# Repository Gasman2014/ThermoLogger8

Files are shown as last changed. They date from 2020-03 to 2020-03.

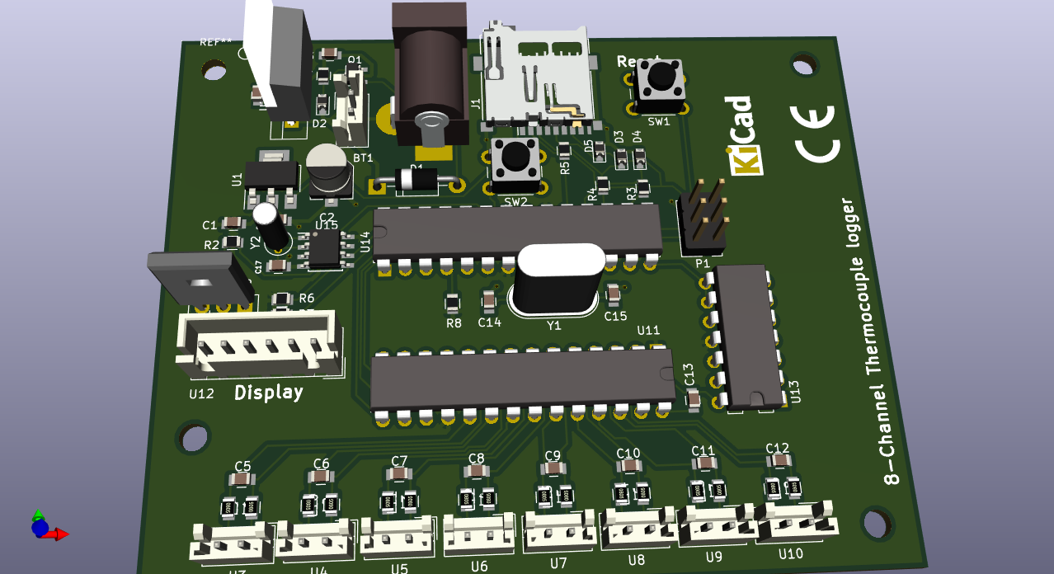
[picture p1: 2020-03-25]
Ver_5V/Renders:STEP/ca9ed02408.png

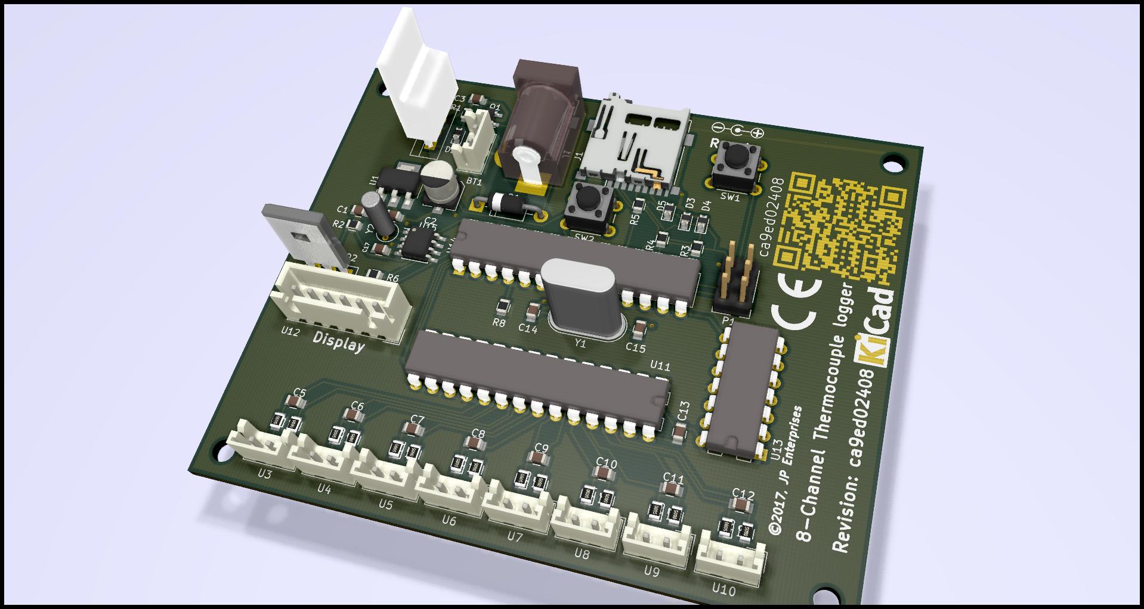
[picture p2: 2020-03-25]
Ver_5V/Renders:STEP/ca9ed02408.jpg

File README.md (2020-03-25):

# ThermoLogger8

Just quickly pushed this repo if anyone is interested. It works in bradboard format and I have designed a PCB in KiCad. There is a 5v and 
a 3.3v version depending on choice of MC. I have been using Fosil as a VCS for this project and have just pushed the whole repo to GitHub.
If you are interested in the development history I could add the Fossil.repo.

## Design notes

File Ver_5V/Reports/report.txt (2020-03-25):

Info: Reading netlist file “/Users/johnpateman/EDA_Workspace/Projects/Thermocouple_datalogger/Ver_5V/ThermocoupleLogger.net”.

Info: Using references to match components and footprints.

Warning: Footprint of symbol "P2" changed: board footprint "Connectors_JST:JST_XH_B04B-XH-A_04x2.50mm_Straight", netlist footprint "Connector_JST:JST_XH_B04B-XH-A_1x04_P2.50mm_Vertical"

Warning: Footprint of symbol "C3" changed: board footprint "Capacitors_SMD:C_0805", netlist footprint "Capacitor_SMD:CP_Elec_4x4.5"

Warning: Footprint of symbol "C4" changed: board footprint "Capacitors_SMD:C_0805", netlist footprint "Capacitor_SMD:CP_Elec_4x4.5"

Info: Checking netlist symbol footprint "BT1:/583C9FB7/5930D2E0:Connectors_JST:JST_XH_B02B-XH-A_02x2.50mm_Straight".

Info: Checking netlist symbol footprint "BT2:/589D87C6/589D8986:Battery_Holders:Keystone_103_1x20mm-CoinCell".

Info: Checking netlist symbol footprint "C1:/583C9FB7/5915D301:Capacitors_SMD:C_0805".

Info: Checking netlist symbol footprint "C2:/583C9FB7/59526106:Capacitors_SMD:CP_Elec_5x5.3".

Info: Checking netlist symbol footprint "C3:/583C9FB7/594D1F83:Capacitor_SMD:CP_Elec_4x4.5".

Changing footprint "C3:/583C9FB7/594D1F83" value from "0.33uF" to "1uF".

Info: Checking netlist symbol footprint "C4:/583C9FB7/589F9200:Capacitor_SMD:CP_Elec_4x4.5".

Changing footprint "C4:/583C9FB7/589F9200" value from "0.1uF" to "10uF".

Info: Checking netlist symbol footprint "C5:/589CE548/589D5633:Capacitors_SMD:C_0805".

Info: Checking netlist symbol footprint "C6:/589CE548/589D5A27:Capacitors_SMD:C_0805".

Info: Checking netlist symbol footprint "C7:/589CE548/589D5A90:Capacitors_SMD:C_0805".

Info: Checking netlist symbol footprint "C8:/589CE548/589D5AFD:Capacitors_SMD:C_0805".

Info: Checking netlist symbol footprint "C9:/589CE548/589D5B98:Capacitors_SMD:C_0805".

Info: Checking netlist symbol footprint "C10:/589CE548/589D9FEC:Capacitors_SMD:C_0805".

Info: Checking netlist symbol footprint "C11:/589CE548/589DA065:Capacitors_SMD:C_0805".

Info: Checking netlist symbol footprint "C12:/589CE548/589DA428:Capacitors_SMD:C_0805".

Info: Checking netlist symbol footprint "C13:/589D87C6/5915E444:Capacitors_SMD:C_0805".

Info: Checking netlist symbol footprint "C14:/589D87C6/59161BEE:Capacitors_SMD:C_0805".

Info: Checking netlist symbol footprint "C15:/589D87C6/59161C96:Capacitors_SMD:C_0805".

Info: Checking netlist symbol footprint "C16:/589D87C6/594D3028:Capacitors_SMD:C_0805".

Info: Checking netlist symbol footprint "C17:/589D87C6/594D308E:Capacitors_SMD:C_0805".

Info: Checking netlist symbol footprint "D1:/583C9FB7/594BF20E:Diodes_THT:D_DO-41_SOD81_P10.16mm_Horizontal".

Changing footprint "D1:/583C9FB7/594BF20E" pad "2" net name from "Net-(D1-Pad2)" to "/Thermocouple_PSU/Supply".

Info: Checking netlist symbol footprint "D2:/583C9FB7/594BFB6D:Diodes_SMD:D_SOD-323".

Info: Checking netlist symbol footprint "D3:/589D5546/59314520:Diodes_SMD:D_SOD-123".

Info: Checking netlist symbol footprint "D4:/589D5546/593144F7:Diodes_SMD:D_SOD-123".

Info: Checking netlist symbol footprint "D5:/589D5546/59314274:Diodes_SMD:D_SOD-123".

Info: Checking netlist symbol footprint "J1:/583C9FB7/5930D1C5:Connectors:BARREL_JACK".

Changing footprint "J1:/583C9FB7/5930D1C5" pad "2" net name from "Net-(D1-Pad2)" to "/Thermocouple_PSU/Supply".

Info: Checking netlist symbol footprint "L1:/589CE548/59318E46:Inductor_SMD:L_0805_2012Metric".

Changing footprint "L1:/589CE548/59318E46" value from "150Ω" to "150".

Info: Checking netlist symbol footprint "L2:/589CE548/594D1477:Inductor_SMD:L_0805_2012Metric".

Changing footprint "L2:/589CE548/594D1477" value from "150Ω" to "150".

Info: Checking netlist symbol footprint "L3:/589CE548/594D14C5:Inductor_SMD:L_0805_2012Metric".

Changing footprint "L3:/589CE548/594D14C5" value from "150Ω" to "150".

Info: Checking netlist symbol footprint "L4:/589CE548/594D1517:Inductor_SMD:L_0805_2012Metric".

Changing footprint "L4:/589CE548/594D1517" value from "150Ω" to "150".

Info: Checking netlist symbol footprint "L5:/589CE548/594D156A:Inductor_SMD:L_0805_2012Metric".

Changing footprint "L5:/589CE548/594D156A" value from "150Ω" to "150".

Info: Checking netlist symbol footprint "L6:/589CE548/594D1615:Inductor_SMD:L_0805_2012Metric".

Changing footprint "L6:/589CE548/594D1615" value from "150Ω" to "150".

Info: Checking netlist symbol footprint "L7:/589CE548/594D1669:Inductor_SMD:L_0805_2012Metric".

Changing footprint "L7:/589CE548/594D1669" value from "150Ω" to "150".

Info: Checking netlist symbol footprint "L8:/589CE548/594D16C4:Inductor_SMD:L_0805_2012Metric".

Changing footprint "L8:/589CE548/594D16C4" value from "150Ω" to "150".

Info: Checking netlist symbol footprint "L9:/589CE548/594D1429:Inductor_SMD:L_0805_2012Metric".

Changing footprint "L9:/589CE548/594D1429" value from "150Ω" to "150".

Info: Checking netlist symbol footprint "L10:/589CE548/594D1721:Inductor_SMD:L_0805_2012Metric".

Changing footprint "L10:/589CE548/594D1721" value from "150Ω" to "150".

Info: Checking netlist symbol footprint "L11:/589CE548/594D177B:Inductor_SMD:L_0805_2012Metric".

Changing footprint "L11:/589CE548/594D177B" value from "150Ω" to "150".

Info: Checking netlist symbol footprint "L12:/589CE548/594D17DD:Inductor_SMD:L_0805_2012Metric".

Changing footprint "L12:/589CE548/594D17DD" value from "150Ω" to "150".

Info: Checking netlist symbol footprint "L13:/589CE548/594D183D:Inductor_SMD:L_0805_2012Metric".

Changing footprint "L13:/589CE548/594D183D" value from "150Ω" to "150".

Info: Checking netlist symbol footprint "L14:/589CE548/594D18A4:Inductor_SMD:L_0805_2012Metric".

Changing footprint "L14:/589CE548/594D18A4" value from "150Ω" to "150".

Info: Checking netlist symbol footprint "L15:/589CE548/594D190A:Inductor_SMD:L_0805_2012Metric".

Changing footprint "L15:/589CE548/594D190A" value from "150Ω" to "150".

Info: Checking netlist symbol footprint "L16:/589CE548/594D1971:Inductor_SMD:L_0805_2012Metric".

Changing footprint "L16:/589CE548/594D1971" value from "150Ω" to "150".

Info: Checking netlist symbol footprint "P1:/589D87C6/589E4CA3:Pin_Headers:Pin_Header_Straight_2x03_Pitch2.54mm".

Info: Checking netlist symbol footprint "P2:/589D87C6/5AF4BC3D:Connector_JST:JST_XH_B04B-XH-A_1x04_P2.50mm_Vertical".

Changing footprint "P2:/589D87C6/589D89DF" value from "CONN_01X04" to "Conn_01x04".

Info: Changing component path “P2:/589D87C6/589D89DF” to “/589D87C6/5AF4BC3D”.

Info: Checking netlist symbol footprint "Q1:/583C9FB7/594BC4B0:TO_SOT_Packages_SMD:TSOT-23".

Changing footprint "Q1:/583C9FB7/594BC4B0" pad "1" net name from "Net-(D1-Pad2)" to "/Thermocouple_PSU/Supply".

Info: Checking netlist symbol footprint "Q2:/589D5546/589EBCEC:TO_SOT_Packages_THT:TO-126_Vertical".

Info: Checking netlist symbol footprint "R1:/583C9FB7/594BF93F:Resistors_SMD:R_0805".

Info: Checking netlist symbol footprint "R2:/589D5546/589EBC96:Resistors_SMD:R_0805".

Info: Checking netlist symbol footprint "R3:/589D5546/59314B9F:Resistors_SMD:R_0805".

Info: Checking netlist symbol footprint "R4:/589D5546/59314AC7:Resistors_SMD:R_0805".

Info: Checking netlist symbol footprint "R5:/589D5546/59314C06:Resistors_SMD:R_0805".

Info: Checking netlist symbol footprint "R6:/589D87C6/589D89D8:Resistors_SMD:R_0805".

Info: Checking netlist symbol footprint "R7:/589D87C6/589D89CE:Resistors_SMD:R_0805".

Info: Checking netlist symbol footprint "R8:/589D87C6/589D89B6:Resistors_SMD:R_0805".

Info: Checking netlist symbol footprint "SW1:/589D87C6/59308FE2:Buttons_Switches_THT:SW_PUSH_6mm_h5mm".

Info: Checking netlist symbol footprint "SW2:/589D87C6/5930906F:Buttons_Switches_THT:SW_PUSH_6mm_h5mm".

Info: Checking netlist symbol footprint "U1:/583C9FB7/59525E1F:TO_SOT_Packages_SMD:SOT-223".

Info: Checking netlist symbol footprint "U2:/583C9FB7/594D2B25:TO_SOT_Packages_THT:TO-220_Vertical".

Info: Checking netlist symbol footprint "U3:/589CE548/589CECB5:Connectors_JST:JST_XH_B02B-XH-A_02x2.50mm_Straight".

Info: Checking netlist symbol footprint "U4:/589CE548/589CECBF:Connectors_JST:JST_XH_B02B-XH-A_02x2.50mm_Straight".

Info: Checking netlist symbol footprint "U5:/589CE548/589CECC9:Connectors_JST:JST_XH_B02B-XH-A_02x2.50mm_Straight".

Info: Checking netlist symbol footprint "U6:/589CE548/589CECD3:Connectors_JST:JST_XH_B02B-XH-A_02x2.50mm_Straight".

Info: Checking netlist symbol footprint "U7:/589CE548/589CECDD:Connectors_JST:JST_XH_B02B-XH-A_02x2.50mm_Straight".

Info: Checking netlist symbol footprint "U8:/589CE548/589CECE7:Connectors_JST:JST_XH_B02B-XH-A_02x2.50mm_Straight".

Info: Checking netlist symbol footprint "U9:/589CE548/589CECF1:Connectors_JST:JST_XH_B02B-XH-A_02x2.50mm_Straight".

Info: Checking netlist symbol footprint "U10:/589CE548/589CECFB:Connectors_JST:JST_XH_B02B-XH-A_02x2.50mm_Straight".

Info: Checking netlist symbol footprint "U11:/589CE548/589D71A8:Housings_DIP:DIP-28_W15.24mm".

Info: Checking netlist symbol footprint "U12:/589D5546/589D6D78:Connectors_JST:JST_XH_B06B-XH-A_06x2.50mm_Straight".

Info: Checking netlist symbol footprint "U13:/589D87C6/589E58D9:Housings_DIP:DIP-14_W7.62mm".

Info: Checking netlist symbol footprint "U14:/589D87C6/593091B0:Housings_DIP:DIP-28_W7.62mm".

Info: Checking netlist symbol footprint "U15:/589D87C6/593095B6:Housings_SOIC:SOIC-8_3.9x4.9mm_Pitch1.27mm".

Info: Checking netlist symbol footprint "XS1:/589D5546/59544647:jp_personal:Conn_uSDcard".

Info: Checking netlist symbol footprint "Y1:/589D87C6/589E8900:Crystals:Crystal_HC49-U_Vertical".

Info: Checking netlist symbol footprint "Y2:/589D87C6/589D897F:Crystals:Crystal_Round_d3.0mm_Vertical".

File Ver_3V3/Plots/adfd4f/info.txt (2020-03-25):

uuid:         adfd4f66951eeb5335d1c4a91e0210d5d108aa21 2017-11-17 14:26:38 UTC
parent:       d7c0fee4f85c9370c295e011c4474d3fdc0f855e 2017-11-03 09:44:51 UTC
tags:         parallel_connector
comment:      Adjusted footprint for battery to JST-XH series (user: johnpateman)

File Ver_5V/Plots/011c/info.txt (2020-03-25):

uuid:         011c27aa1c76feabf7278f71abef9c959f46e682 2018-12-18 12:02:45 UTC
parent:       52bd0d96c514364f6365ff9b00088230d3ec4453 2018-12-17 20:01:36 UTC
tags:         Ver_5V
comment:      Updated entire board with Kicad V5.0.2 stock footprints (apart from custom SD Card) (user: johnpateman)

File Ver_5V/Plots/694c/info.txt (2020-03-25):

uuid:         694c0817d49da92233c9e31c0feafe5217195195 2018-12-01 09:59:20 UTC
parent:       5034922709994dd389909f162e60e1b737ea69a4 2018-11-30 19:22:05 UTC
child:        162a23e4f3287c9c34212c83937c62a5d8ec3218 2018-12-17 20:04:35 UTC
tags:         parallel_connector
comment:      Updated multiple components with new component numbers to match PartKeepr database. Rerun KiBOM. The .csv file in this commit has had the Display line removed.
              Need to remove the display line as this seem to cause the K2PK script to fail - it continues to look up all component in the database. Probably related to this
              component not having a specific footprint. (user: johnpateman)

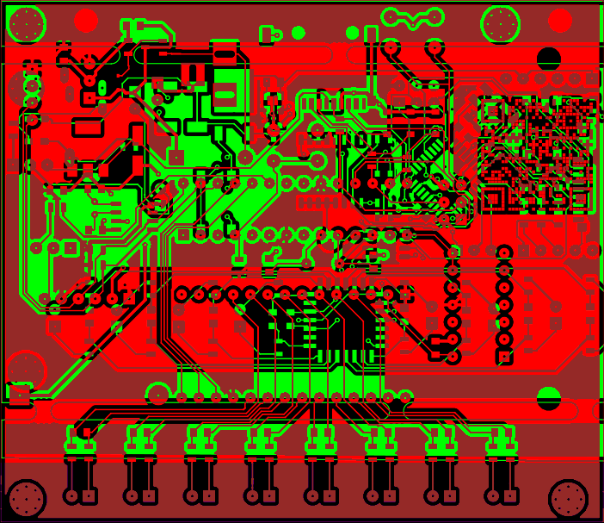
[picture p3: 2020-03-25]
Ver_3V3/Plots/diff-adfd4f-620aab/ThermocoupleLogger-F_Cu.png

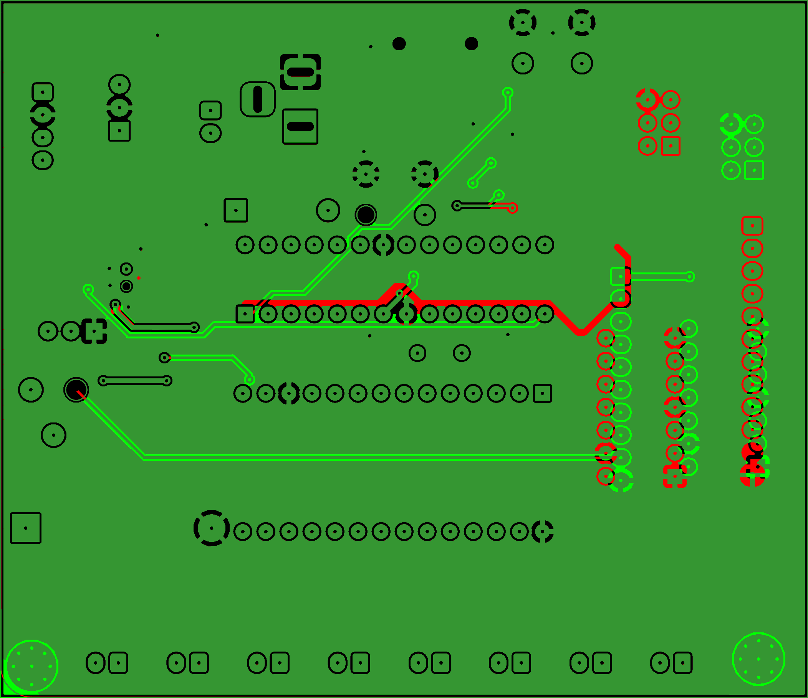
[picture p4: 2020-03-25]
Ver_5V/Plots/diff-3c9fec-b2096b/ThermocoupleLogger-B_Cu.png

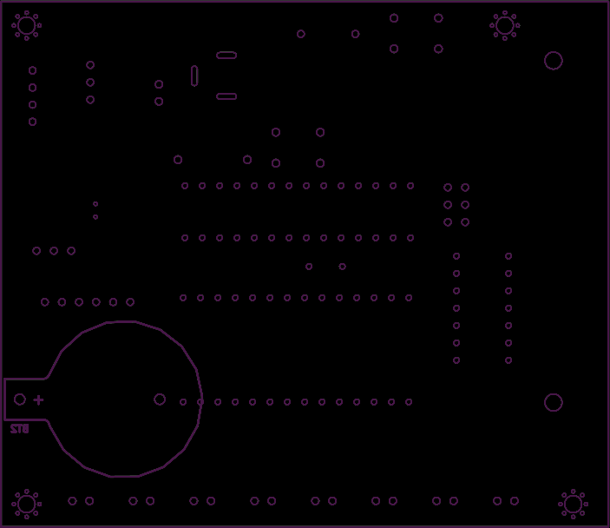
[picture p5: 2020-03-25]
Ver_3V3/Plots/620aab/ThermocoupleLogger-B_SilkS.png

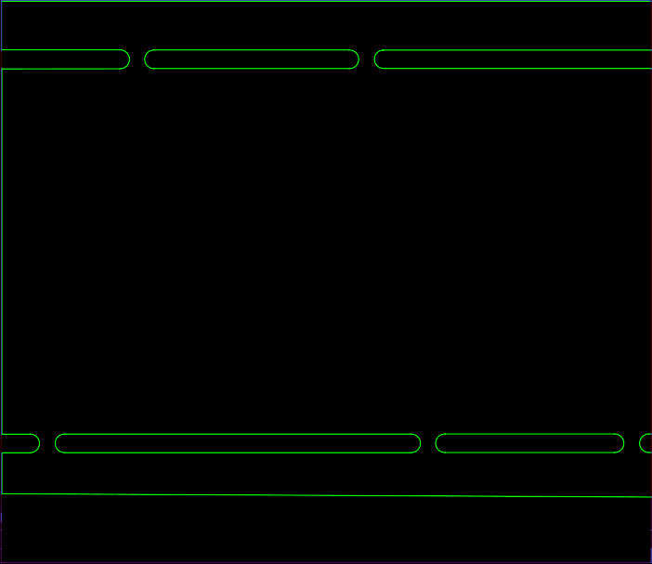
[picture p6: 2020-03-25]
Ver_3V3/Plots/diff-adfd4f-620aab/ThermocoupleLogger-B_Adhes.png

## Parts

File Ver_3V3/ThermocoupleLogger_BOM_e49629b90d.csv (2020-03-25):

Component | Description | Part | References | Value | Footprint | Quantity Per PCB | Datasheet | Part# | Placement | Package_ID | Characteristics | C3 C16 C17 C18 C20 C21 C22 | 100nF 0805 | 7 | C_0805 | 7
1 | Multiple-cell battery | Battery | BT2 | 3V [CR2032] | Keystone_106_1x20mm-CoinCell | 1 |  | KEYSTONE 103 | - | - | - | C6 C7 C8 C9 C10 C11 C12 C13 C14 C15 C19 | 10nF 0805 | 11 | C_0805 | 11
2 | Multiple-cell battery | Battery | BT1 | Battery | JST_XH_B02B-XH-A_1x02_P2.50mm_Vertical | 1 |  | B2B-XH-A(LF)(SN) | - | - | - | C4 | 10uF 0805 | 1 | C_0805 | 1
3 | Unpolarized capacitor, small symbol | C_Small | C3 C16 C17 C18 C20 C21 C22 | 100nF | C_0805 | 7 |  | - | - | - | - | C5 | 1uF 0805 | 1 | C_0805 | 1
4 | Polarized capacitor, small symbol | CP_Small | C1 C2 | 100uF | CP_Elec_5x5.3 | 2 |  | EEEFT1C101AR | - | - | - | D2 D3 | 1N4448W-7-F SOD-123 | 2 | D_ | 2
5 | Unpolarized capacitor, small symbol | C_Small | C6 C7 C8 C9 C10 C11 C12 C13 C14 C15 C19 | 10nF | C_0805 | 11 |  | - | - | - | - | IC1 | ATMEGA328-P | 1 | TQFP-32_7x7mm_Pitch0.8mm | 1
6 | Polarized capacitor, small symbol | CP_Small | C4 | 10uF | C_0805 | 1 |  | - | - | - | - | J1 | FC68127 | 1 | CLIFF_FC68127 | 1
7 | Unpolarized capacitor, small symbol | C_Small | C5 | 1uF | C_0805 | 1 |  | - | - | - | - | L1 L2 L3 L4 L5 L6 L7 L8 L9 L10 L11 L12 L13 L14 L15 L16 | Ferrite 100 Ohms 10MHz 0805 | 16 | L_0805 | 16
8 | SD Card Reader | SD_Card | CON1 | SD_Card | Conn_uSDcard | 1 | http://portal.fciconnect.com/Comergent//fci/drawing/10067847.pdf | SD_Card[uSD] | - | - | - | P1 | Conn_02x03_Top_Bottom | 1 | PinHeader_2x03_P2.54mm_Vertical | 1
9 | 50V 1A General Purpose Rectifier Diode, DO-41 | 1N4001 | D2 D3 | 1N4448W-7-F | D_SOD-123 | 2 | http://www.vishay.com/docs/88503/1n4001.pdf | 1N4448W-7-F | - | - | - | Q1 | MMBT3904LT1G | 1 | SOT-23 | 1
10 | Dual LED, common cathode on pin 2 | LED_Dual_ACA | D1 | LED_Dual_ACA | LED_D3.0mm-3 | 1 |  | L-93WEGW | - | - | - | R3 R4 R10 | 10k | 3 | R_0805 | 3
11 |  | ATMEGA328P-AU-RESCUE-ThermocoupleLogger | IC1 | ATMEGA328-P | TQFP-32_7x7mm_Pitch0.8mm | 1 |  | ATMEGA328P-AU | - | - | - | R5 R6 R7 | 22k | 3 | R_0805 | 3
12 | Generic connector, single row, 01x03, script generated (kicad-library-utils/schlib/autogen/connector/) | Conn_01x03 | J2 | CONN_01X03 | Pin_Header_Straight_1x03_Pitch2.54mm | 1 |  | B3B-XH-A(LF)(SN) | - | - | - | R11 | 330R | 1 | R_0805 | 1
13 | Generic connector, single row, 01x05, script generated (kicad-library-utils/schlib/autogen/connector/) | Conn_01x05 | J3 | CONN_01X05 | PinHeader_1x05_P2.54mm_Vertical | 1 |  | B5B-XH-A(LF)(SN) | - | - | - | R8 R9 | 4.7k | 2 | R_0805 | 2
14 | Jack socket, 3.5mm, 4-Pole | FC68127 | J1 | FC68127 | CLIFF_FC68127 | 1 | FC68127 | FC68127 | - | - | - | R1 R2 | 750R | 2 | R_0805 | 2
15 | Ferrite bead, small symbol | Ferrite_Bead_Small | L1 L2 L3 L4 L5 L6 L7 L8 L9 L10 L11 L12 L13 L14 L15 L16 | 100 Ohms 10MHz | L_0805 | 16 |  | MPZ2012S101A | - | - | - | SW2 SW3 | SW_PUSH | 2 | SW_PUSH_6mm_H4.3mm | 2
16 | Generic connector, double row, 02x03, top/bottom pin numbering scheme (row 1: 1...pins_per_row, row2: pins_per_row+1 ... num_pins), script generated (kicad-library-utils/schlib/autogen/connector/) | Conn_02x03_Top_Bottom | P1 | Conn_02x03_Top_Bottom | PinHeader_2x03_P2.54mm_Vertical | 1 |  | 75869-131LF | - | - | - | SW1 | SW_SPST | 1 | JST_XH_B02B-XH-A_1x02_P2.50mm_Vertical | 1
17 | 0.2A Ic, 40V Vce, Small Signal NPN Transistor, SOT-23 | MMBT3904 | Q1 | MMBT3904LT1G | SOT-23 | 1 | http://www.fairchildsemi.com/ds/BC/BC817.pdf | MMBT3904LT1G | - | - | - | U4 | ADG407BPZ | 1 | PLCC-28 | 1
18 | Resistor, small symbol | R_Small | R3 R4 R10 | 10k | R_0805 | 3 |  | - | - | - | - | U13 | DS3231 | 1 | SOIC-16W_7.5x10.3mm_Pitch1.27mm | 1
19 | Resistor, small symbol | R_Small | R5 R6 R7 | 22k | R_0805 | 3 |  | - | - | - | - | U1 | LF50_TO252 | 1 | TO-252-3_TabPin4 | 1
20 | Resistor, small symbol | R_Small | R11 | 330R | R_0805 | 1 |  | - | - | - | - | U14 | MAX31855KASA | 1 | SOIC-8_3.9x4.9mm_P1.27mm | 1
21 | Resistor | R | R8 R9 | 4.7k | R_0805 | 2 |  | - | - | - | - | U2 | RT9166-33GVL | 1 | SOT-23 | 1
22 | Resistor, small symbol | R_Small | R1 R2 | 750R | R_0805 | 2 |  | - | - | - | - | U3 U5 U6 U7 U8 U9 U10 U11 | TC_Connector | 8 | JST_XH_B02B-XH-A_1x02_P2.50mm_Vertical | 8
23 | Push button switch, generic, two pins | SW_Push | SW2 SW3 | SW_PUSH | SW_PUSH_6mm_H4.3mm | 2 |  | SKHHAJA010 | - | - | - | Y1 | Crystal_8MHz | 1 | Crystal_SMD_Abracon_ABM3B-4pin_5.0x3.2mm | 1
24 | Single Pole Single Throw (SPST) switch | SW_SPST | SW1 | SW_SPST | JST_XH_B02B-XH-A_1x02_P2.50mm_Vertical | 1 |  | B2B-XH-A(LF)(SN) | - | - | -
25 | ADG406/407/426_Analog Multiplexer | ADG407 | U4 | ADG407BPZ | PLCC-28 | 1 | http://www.analog.com/media/en/technical-documentation/data-sheets/ADG406_407_426.pdf | ADG407BPZ | - | - | -
26 |  | DS3231M | U13 | DS3231 | SOIC-16W_7.5x10.3mm_Pitch1.27mm | 1 |  | DS3231M+ | - | - | -
28 |  | 7805-RESCUE-ThermocoupleLogger | U1 | LF50_TO252 | TO-252-3_TabPin4 | 1 |  | LF50ABDT-TR | - | - | -
29 | Cold Junction K-type Thermocouple Interface, SPI, SO8 | MAX31855KASA | U14 | MAX31855KASA | SOIC-8_3.9x4.9mm_P1.27mm | 1 | http://datasheets.maximintegrated.com/en/ds/MAX31855.pdf | MAX31855KASA | - | - | -
30 | Low Quiescent Current LDO Regulator, 3.3V, 250 mA, Vin<=16V, SOT-23 | MCP1703A-3302_SOT23 | U2 | RT9166-33GVL | SOT-23 | 1 | http://ww1.microchip.com/downloads/en/DeviceDoc/20005122B.pdf | RT9166-33GVL | - | - | -
31 | TC_Connector | TC_Connector | U3 U5 U6 U7 U8 U9 U10 U11 | TC_Connector | JST_XH_B02B-XH-A_1x02_P2.50mm_Vertical | 8 |  | B2B-XH-A(LF)(SN) | - | - | -
32 | Four pin crystal, GND on pins 2 and 4 | Crystal_GND24 | Y1 | Crystal_8MHz | Crystal_SMD_Abracon_ABM3B-4pin_5.0x3.2mm | 1 |  | ABM3B-8.000MHZ-B2-T |  | - | -
Component Groups: | 32
Component Count: | 79
Fitted Components: | 79
Number of PCBs: | 1
Total components: | 79
Schematic Version: | e49629b90d
Schematic Date: | 11/06/18
BoM Date: | Saturday, 01 December 2018 at 09:49:37
Schematic Source: | /Users/johnpateman/EDA_Workspace/Projects/Thermocouple_datalogger/Ver_3V3/ThermocoupleLogger.sch
KiCad Version: | Eeschema (5.0.1-3-g963ef8bb5)

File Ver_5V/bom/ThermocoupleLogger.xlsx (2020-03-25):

Prj: | 8-Channel Thermocouple Datalogger |  |  |  |  |  | Board Qty: | 100
Co.: | JP Enterprises |  |  |  |  |  | Unit Cost: | $0.00
Prj date: | Friday, 29 June 2018 at 12:55:12 |  |  |  |  |  | Total Cost: | $0.00 |  |  |  | $0.00 | 0 |  |  |  | $0.00 | 0 |  |  |  | $0.00 | 0 |  |  |  | $0.00 | 0 |  |  |  | $0.00 | 0 |  |  |  | $0.00 | 0
$ date: | 2018-07-04 23:36:02
Global Part Info |  |  |  |  |  |  |  |  | Digi-Key |  |  |  |  | Farnell |  |  |  |  | Mouser |  |  |  |  | Newark |  |  |  |  | Rs Components |  |  |  |  | Tme
Refs | Value | Desc | Footprint | Manf | Manf# | Qty | Unit$ | Ext$ | Avail | Purch | Unit$ | Ext$ | Cat# | Avail | Purch | Unit$ | Ext$ | Cat# | Avail | Purch | Unit$ | Ext$ | Cat# | Avail | Purch | Unit$ | Ext$ | Cat# | Avail | Purch | Unit$ | Ext$ | Cat# | Avail | Purch | Unit$ | Ext$ | Cat#
BT1 | 9V | - | Connectors_JST:JST_XH_B02B-XH-A_02x2.50mm_Straight |  | JST-B2B-XH-A | 0 | $0.00 | $0.00
BT2 | Battery | - | Battery_Holders:Keystone_103_1x20mm-CoinCell |  | KEYSTONE 103 | 0 | $0.00 | $0.00
C1 | 470nF | - | Capacitors_SMD:C_0805 |  | - | 0 | $0.00 | $0.00
C13 | 10nF | - | Capacitors_SMD:C_0805 |  | C_0805_X7R_10NF | 0 | $0.00 | $0.00
C14,C15 | 18pF | - | Capacitors_SMD:C_0805 |  | - | 0 | $0.00 | $0.00
C16,C17 | 12.5pF | - | Capacitors_SMD:C_0805 |  | - | 0 | $0.00 | $0.00
C2 | 47uF | - | Capacitors_SMD:CP_Elec_5x5.3 |  | CPE_C_47UF_16V | 0 | $0.00 | $0.00
C3 | 1uF | - | Capacitors_SMD:C_0805 |  | - | 0 | $0.00 | $0.00
C4 | 10uF | - | Capacitor_SMD:CP_Elec_4x5.4 |  | - | 0 | $0.00 | $0.00
C5-C12 | 10nF | C5-C10,C12: - C11: X7R | Capacitors_SMD:C_0805 |  | - | 0 | $0.00 | $0.00
D1 | 1N4007 | - | Diodes_THT:D_DO-41_SOD81_P10.16mm_Horizontal |  | 1N4007 | 0 | $0.00 | $0.00 |  |  |  |  |  | NonStk |  |  |  | 1467514 (http://it.farnell.com/on-semiconductor/1n4007/diodo-standard-1a-1000v-do-41/dp/1467514?st=1N4007) |  |  |  |  |  | NonStk |  | $0.00 | $0.00 | 10M2939 (http://www.newark.com/nte-electronics/1n4007/standard-diode-1a-1kv-do-41/dp/10M2939?st=1N4007) |  |  |  |  |  | 492550 |  | $0.00 | $0.00 | 1N4007-DC (https://www.tme.eu/en/details/1n4007-dc/tht-universal-diodes/dc-components/1n4007/)
D2 | 9V | - | Diodes_SMD:D_SOD-323 |  | BAT60JFILM | 0 | $0.00 | $0.00 | 40878 |  | $0.00 | $0.00 | 497-3707-1-ND (https://www.digikey.com/product-detail/en/stmicroelectronics/BAT60JFILM/497-3707-1-ND/686425) |  |  |  |  |  |  |  |  |  |  |  |  |  |  |  | 800 |  | $0.00 | $0.00 | 714-6879 (http://it.rs-online.com/web/p/diodi-rettificatori-e-schottky/7146879/)
D3-D5 | 3.3V | - | Diodes_SMD:D_SOD-123 |  | BZT52C3V3-7-F | 0 | $0.00 | $0.00 | 34534 |  | $0.00 | $0.00 | BZT52C3V3-FDICT-ND (https://www.digikey.com/product-detail/en/diodes-incorporated/BZT52C3V3-7-F/BZT52C3V3-FDICT-ND/717854) | 11859 |  | $0.00 | $0.00 | 1843704 (http://it.farnell.com/diodes-inc/bzt52c3v3-7-f/diodo-zener-3-3v-0-5w-sod-123/dp/1843704?st=BZT52C3V3-7-F) |  |  |  |  |  | 5525 |  | $0.00 | $0.00 | 12T1447 (http://www.newark.com/webapp/wcs/stores/servlet/Search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) | 27000 |  | $0.00 | $0.00 | 122-0905 (http://it.rs-online.com/web/p/diodi-zener/1220905/) | 4430 |  | $0.00 | $0.00 | BZT52C3V3-7-F (https://www.tme.eu/en/details/bzt52c3v3-7-f/smd-zener-diodes/diodes-incorporated/)
J1 | Barrel_Jack | - | Connectors:BARREL_JACK |  | MJ-179PH | 0 | $0.00 | $0.00
L1-L16 | 150 | - | Inductor_SMD:L_0805_2012Metric |  | MPZ2012S101A | 0 | $0.00 | $0.00 | NonStk |  | $0.00 | $0.00 | 445-172903-1-ND (https://www.digikey.com/product-detail/en/tdk-corporation/MPZ2012S101ATD25/445-172903-1-ND/5040534) |  |  |  |  |  |  |  |  |  |  |  |  |  |  |  | NonStk |  | $0.00 | $0.00 | 604-2202 (http://it.rs-online.com/web/c/?searchTerm=MPZ2012S101A)
P1 | CONN_02X03 | - | Pin_Headers:Pin_Header_Straight_2x03_Pitch2.54mm |  | - | 0 | $0.00 | $0.00
P2 | Conn_01x04 | - | Connector_JST:JST_XH_B04B-XH-A_1x04_P2.50mm_Vertical |  | - | 0 | $0.00 | $0.00
Q1 | BS250 | - | TO_SOT_Packages_SMD:TSOT-23 |  | BS250FTA | 0 | $0.00 | $0.00 | 727 |  | $0.00 | $0.00 | BS250FCT-ND (https://www.digikey.com/product-detail/en/diodes-incorporated/BS250FTA/BS250FCT-ND/53566) | 2332 |  | $0.00 | $0.00 | 1843731 (http://it.farnell.com/diodes-inc/bs250fta/mosfet-canale-p-45v-0-09a-sot23/dp/1843731?st=BS250FTA) | 313 |  | $0.00 | $0.00 | 522-BS250FTA (https://eu.mouser.com/Search/Refine.aspx?Keyword=BS250FTA) | 2352 |  | $0.00 | $0.00 | 12T1444 (http://www.newark.com/webapp/wcs/stores/servlet/Search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) | 170 |  |  |  | 215-6593 (http://it.rs-online.com/web/p/transistor-mosfet/2156593/)
Q2 | BD139 | - | TO_SOT_Packages_THT:TO-126_Vertical |  | BD139 | 0 | $0.00 | $0.00 | NonStk |  | $0.00 | $0.00 | 497-6656-5-ND (https://www.digikey.com/product-detail/en/stmicroelectronics/BD139/497-6656-5-ND/1037682) | 2409 |  | $0.00 | $0.00 | 9556052 (http://it.farnell.com/on-semiconductor/bd139g/transistor-npn-to-225aa/dp/9556052?st=BD139) |  |  |  |  |  | NonStk |  | $0.00 | $0.00 | 33X4079 (http://www.newark.com/stmicroelectronics/bd139/bipolar-bjt-single-transistor/dp/33X4079?st=BD139) | NonStk |  |  |  | 314-1823 (http://it.rs-online.com/web/p/transistor-bipolari/3141823/) | NonStk |  | $0.00 | $0.00 | BD139 (https://www.tme.eu/en/details/bd139/npn-tht-transistors/st-microelectronics/)
R1,R2,R8 | 10K | - | Resistors_SMD:R_0805 |  | RC0805JR-0710KL | 0 | $0.00 | $0.00 | NonStk |  | $0.00 | $0.00 | 311-10KARCT-ND (https://www.digikey.com/product-detail/en/yageo/RC0805JR-0710KL/311-10KARCT-ND/731188) | 10301 |  | $0.00 | $0.00 | 9234136 (http://it.farnell.com/yageo/rc0805jr-0710kl/res-film-spesso-10k-5-0-125w-0805/dp/9234136?st=RC0805JR-0710KL) |  |  |  |  |  | 17748 |  | $0.00 | $0.00 | 68R0258 (http://www.newark.com/yageo/rc0805jr-0710kl/res-thick-film-10k-5-0-125w-0805/dp/68R0258?st=RC0805JR-0710KL) |  |  |  |  |  | 523600 |  | $0.00 | $0.00 | RC0805JR-0710K (https://www.tme.eu/en/details/rc0805jr-0710k/0805-smd-resistors/yageo/rc0805jr-0710kl/)
R6,R7 | 5.1K | - | Resistors_SMD:R_0805 |  | RC0805JR-075K1L | 0 | $0.00 | $0.00 | 301483 |  | $0.00 | $0.00 | 311-5.1KARCT-ND (https://www.digikey.com/product-detail/en/yageo/RC0805JR-075K1L/311-5.1KARCT-ND/731285) |  |  |  |  |  |  |  |  |  |  |  |  |  |  |  |  |  |  |  |  | 3000 |  | $0.00 | $0.00 | RC0805JR-075K1 (https://www.tme.eu/en/details/rc0805jr-075k1/0805-smd-resistors/yageo/rc0805jr-075k1l/)
R3-R5 | 220R | - | Resistors_SMD:R_0805 |  | - | 0 | $0.00 | $0.00
SW1,SW2 | SW_Push | - | Buttons_Switches_THT:SW_PUSH_6mm_h5mm |  | - | 0 | $0.00 | $0.00
U1 | LM3940 | - | TO_SOT_Packages_SMD:SOT-223 |  | LM3940IMP-3.3/NOPB | 0 | $0.00 | $0.00 | 13104 |  | $0.00 | $0.00 | LM3940IMP-3.3/NOPBCT-ND (https://www.digikey.com/product-detail/en/texas-instruments/LM3940IMP-3.3-NOPB/LM3940IMP-3.3-NOPBCT-ND/308025) |  |  |  |  |  |  |  |  |  |  |  |  |  |  |  | 2000 |  | $0.00 | $0.00 | 121-8914 (http://it.rs-online.com/web/p/regolatori-di-tensione-low-dropout/1218914/) | NonStk |  | $0.00 | $0.00 | LM3940IMP-3.3 (https://www.tme.eu/en/details/lm3940imp-3.3/ldo-unregulated-voltage-regulators/texas-instruments/lm3940imp-33nopb/)
U11 | ADG407 | - | Housings_DIP:DIP-28_W15.24mm |  | ADG407BNZ | 0 | $0.00 | $0.00 | 57 |  | $0.00 | $0.00 | ADG407BNZ-ND (https://www.digikey.com/products/en?keywords=ADG407BNZ) |  |  |  |  |  |  |  |  |  |  |  |  |  |  |  | 13 |  |  |  | 523-0054 (http://it.rs-online.com/web/p/multiplexer/5230054/)
U12 | I2C_20x4_DISPLAY | - | Connectors_JST:JST_XH_B06B-XH-A_06x2.50mm_Straight |  | JST-B6B-XH-A | 0 | $0.00 | $0.00
U13 | AD595 | - | Housings_DIP:DIP-14_W7.62mm |  | AD595CQ | 0 | $0.00 | $0.00 | 1123 |  | $0.00 | $0.00 | AD595CQ-ND (https://www.digikey.com/products/en?keywords=AD595CQ) | 15 |  | $0.00 | $0.00 | 102052 (http://it.farnell.com/Search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) |  |  |  |  |  | NonStk |  |  |  | 15P0723 (http://www.newark.com/webapp/wcs/stores/servlet/Search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) | 66 |  |  |  | 169-8737 (http://it.rs-online.com/web/p/amplificatori-da-strumentazione/1698737/)
U14 | ATMEGA328P-PU | - | Housings_DIP:DIP-28_W7.62mm |  | ATMEGA328P-PU | 0 | $0.00 | $0.00 | 17406 |  | $0.00 | $0.00 | ATMEGA328P-PU-ND (https://www.digikey.com/products/en?keywords=ATMEGA328P-PU) |  |  |  |  |  |  |  |  |  |  | 5810 |  | $0.00 | $0.00 | 68T2944 (http://www.newark.com/webapp/wcs/stores/servlet/Search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) | NonStk |  | $0.00 | $0.00 | 921-4545 (http://it.rs-online.com/web/p/microcontroller/9214545/) | 2388 |  | $0.00 | $0.00 | ATMEGA328P-PU (https://www.tme.eu/en/details/atmega328p-pu/8-bit-avr-family/microchip-atmel/)
U15 | DS1307+ | - | Housings_SOIC:SOIC-8_3.9x4.9mm_Pitch1.27mm |  | DS1307ZN+ (https://datasheets.maximintegrated.com/en/ds/DS1307.pdf) | 0 | $0.00 | $0.00 | 11632 |  | $0.00 | $0.00 | DS1307ZN+-ND (https://www.digikey.com/product-detail/en/maxim-integrated/DS1307ZN/DS1307ZN-ND/956881) |  |  |  |  |  |  |  |  |  |  |  |  |  |  |  | 13 |  |  |  | 732-7333 (http://it.rs-online.com/web/p/clock-real-time/7327333/) | NonStk |  | $0.00 | $0.00 | DS1307ZN+ (https://www.tme.eu/en/details/ds1307zn+/rtc-circuits/maxim-dallas/)
U2 | 7805 | - | TO_SOT_Packages_THT:TO-220_Vertical |  | L7805CP | 0 | $0.00 | $0.00 | 3113 |  | $0.00 | $0.00 | 497-1442-5-ND (https://www.digikey.com/products/en?keywords=L7805CP) | 9691 |  | $0.00 | $0.00 | 9756434 (http://it.farnell.com/Search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) |  |  |  |  |  | 93 |  | $0.00 | $0.00 | 56P8824 (http://www.newark.com/stmicroelectronics/l7805cp/power-management/dp/56P8824?st=L7805CP) | 99 |  |  |  | 296-756 (http://it.rs-online.com/web/p/regolatori-di-tensione-lineari/0296756/) | 334 |  | $0.00 | $0.00 | L7805CP (https://www.tme.eu/en/details/l7805cp/unregulated-voltage-regulators/st-microelectronics/)
U3-U6 | TC_Connector | - | Connectors_JST:JST_XH_B02B-XH-A_02x2.50mm_Straight |  | JST B2B-XH-A | 0 | $0.00 | $0.00 |  |  |  |  |  |  |  |  |  |  |  |  |  |  |  |  |  |  |  |  |  |  |  |  |  | 1738 |  | $0.00 | $0.00 | B2B-XH-A (https://www.tme.eu/en/details/b2b-xh-a/raster-signal-connectors-250mm/jst/)
U7-U10 | TC_Connector | - | Connectors_JST:JST_XH_B02B-XH-A_02x2.50mm_Straight |  | B2B-XH-A | 0 | $0.00 | $0.00 | 8572 |  | $0.00 | $0.00 | 455-2946-ND (https://www.digikey.com/product-detail/en/jst-sales-america-inc/B2B-XH-A-GU/455-2946-ND/2043065) |  |  |  |  |  |  |  |  |  |  |  |  |  |  |  | 885 |  | $0.00 | $0.00 | 820-1554 (http://it.rs-online.com/web/p/file-di-contatti-da-pcb/8201554/) | 1738 |  | $0.00 | $0.00 | B2B-XH-A (https://www.tme.eu/en/details/b2b-xh-a/raster-signal-connectors-250mm/jst/)
XS1 | SD_ebay-uSD-push/push_SMD | - | jp_personal:Conn_uSDcard | ebay | SD_Card[uSD] | 0 | $0.00 | $0.00 |  |  |  |  |  |  |  |  |  |  |  |  |  |  |  | NonStk |  |  |  | 68X0156 (http://www.newark.com/webapp/wcs/stores/servlet/Search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)
Y1 | 16MHz | 16MHz Vertical crystal | Crystals:Crystal_HC49-U_Vertical |  | FOXSLF/160-20 | 0 | $0.00 | $0.00 | 4462 |  | $0.00 | $0.00 | 631-1108-ND (https://www.digikey.com/products/en?keywords=FOXSLF%2F160-20) |  |  |  |  |  |  |  |  |  |  |  |  |  |  |  | NonStk |  | $0.00 | $0.00 | 173-4298 (http://it.rs-online.com/web/p/cristalli/1734298/)
Y2 | 32.768kHz | - | Crystals:Crystal_Round_d3.0mm_Vertical |  | AB26T-32.768KHZ | 0 | $0.00 | $0.00 | 22872 |  | $0.00 | $0.00 | 535-9032-ND (https://www.digikey.com/product-detail/en/abracon-llc/AB26T-32.768KHZ/535-9032-ND/675227) | 4546 |  | $0.00 | $0.00 | 2467704 (http://it.farnell.com/abracon/ab26t-32-768khz/crystal-32-768khz-12-5pf-cylinder/dp/2467704?st=AB26T-32.768KHZ) |  |  |  |  |  | 4787 |  | $0.00 | $0.00 | 89K0457 (http://www.newark.com/abracon/ab26t-32-768khz/crystal-32-768khz-12-5pf-cylinder/dp/89K0457?st=AB26T-32.768KHZ) | 2590 |  | $0.00 | $0.00 | 171-0553 (http://it.rs-online.com/web/p/cristalli/1710553/)
Distributors scraped by KiCost\N{REGISTERED SIGN} v.0.1.46 |  |  |  |  |  |  |  |  |  | 0 |  |  |  |  | 0 |  |  |  |  | 0 |  |  |  |  | 0 |  |  |  |  | 0 |  |  |  |  | 0
 |  |  |  |  |  |  |  |  |  | 0 | 0 | 0 |  |  | 0 | 0 | 0 |  |  | 0 | 0 | 0 |  |  | 0 | 0 | 0 |  |  | 0 | 0 | 0 |  |  | 0 | 0 | 0
 |  |  |  |  |  |  |  |  |  | 0 | 0 | 0 |  |  | 0 | 0 | 0 |  |  | 0 | 0 | 0 |  |  | 0 | 0 | 0 |  |  | 0 | 0 | 0 |  |  | 0 | 0 | 0
 |  |  |  |  |  |  |  |  |  | 0 | 0 | 0 |  |  | 0 | 0 | 0 |  |  | 0 | 0 | 0 |  |  | 0 | 0 | 0 |  |  | 0 | 0 | 0 |  |  | 0 | 0 | 0
 |  |  |  |  |  |  |  |  |  | 0 | 0 | 0 |  |  | 0 | 0 | 0 |  |  | 0 | 0 | 0 |  |  | 0 | 0 | 0 |  |  | 0 | 0 | 0 |  |  | 0 | 0 | 0
 |  |  |  |  |  |  |  |  |  | 0 | 0 | 0 |  |  | 0 | 0 | 0 |  |  | 0 | 0 | 0 |  |  | 0 | 0 | 0 |  |  | 0 | 0 | 0 |  |  | 0 | 0 | 0
 |  |  |  |  |  |  |  |  |  | 0 | 0 | 0 |  |  | 0 | 0 | 0 |  |  | 0 | 0 | 0 |  |  | 0 | 0 | 0 |  |  | 0 | 0 | 0 |  |  | 0 | 0 | 0
 |  |  |  |  |  |  |  |  |  | 0 | 0 | 0 |  |  | 0 | 0 | 0 |  |  | 0 | 0 | 0 |  |  | 0 | 0 | 0 |  |  | 0 | 0 | 0 |  |  | 0 | 0 | 0
 |  |  |  |  |  |  |  |  |  | 0 | 0 | 0 |  |  | 0 | 0 | 0 |  |  | 0 | 0 | 0 |  |  | 0 | 0 | 0 |  |  | 0 | 0 | 0 |  |  | 0 | 0 | 0
 |  |  |  |  |  |  |  |  |  | 0 | 0 | 0 |  |  | 0 | 0 | 0 |  |  | 0 | 0 | 0 |  |  | 0 | 0 | 0 |  |  | 0 | 0 | 0 |  |  | 0 | 0 | 0
 |  |  |  |  |  |  |  |  |  | 0 | 0 | 0 |  |  | 0 | 0 | 0 |  |  | 0 | 0 | 0 |  |  | 0 | 0 | 0 |  |  | 0 | 0 | 0 |  |  | 0 | 0 | 0
 |  |  |  |  |  |  |  |  |  | 0 | 0 | 0 |  |  | 0 | 0 | 0 |  |  | 0 | 0 | 0 |  |  | 0 | 0 | 0 |  |  | 0 | 0 | 0 |  |  | 0 | 0 | 0
 |  |  |  |  |  |  |  |  |  | 0 | 0 | 0 |  |  | 0 | 0 | 0 |  |  | 0 | 0 | 0 |  |  | 0 | 0 | 0 |  |  | 0 | 0 | 0 |  |  | 0 | 0 | 0
 |  |  |  |  |  |  |  |  |  | 0 | 0 | 0 |  |  | 0 | 0 | 0 |  |  | 0 | 0 | 0 |  |  | 0 | 0 | 0 |  |  | 0 | 0 | 0 |  |  | 0 | 0 | 0
 |  |  |  |  |  |  |  |  |  | 0 | 0 | 0 |  |  | 0 | 0 | 0 |  |  | 0 | 0 | 0 |  |  | 0 | 0 | 0 |  |  | 0 | 0 | 0 |  |  | 0 | 0 | 0
 |  |  |  |  |  |  |  |  |  | 0 | 0 | 0 |  |  | 0 | 0 | 0 |  |  | 0 | 0 | 0 |  |  | 0 | 0 | 0 |  |  | 0 | 0 | 0 |  |  | 0 | 0 | 0
 |  |  |  |  |  |  |  |  |  | 0 | 0 | 0 |  |  | 0 | 0 | 0 |  |  | 0 | 0 | 0 |  |  | 0 | 0 | 0 |  |  | 0 | 0 | 0 |  |  | 0 | 0 | 0
 |  |  |  |  |  |  |  |  |  | 0 | 0 | 0 |  |  | 0 | 0 | 0 |  |  | 0 | 0 | 0 |  |  | 0 | 0 | 0 |  |  | 0 | 0 | 0 |  |  | 0 | 0 | 0
 |  |  |  |  |  |  |  |  |  | 0 | 0 | 0 |  |  | 0 | 0 | 0 |  |  | 0 | 0 | 0 |  |  | 0 | 0 | 0 |  |  | 0 | 0 | 0 |  |  | 0 | 0 | 0
 |  |  |  |  |  |  |  |  |  | 0 | 0 | 0 |  |  | 0 | 0 | 0 |  |  | 0 | 0 | 0 |  |  | 0 | 0 | 0 |  |  | 0 | 0 | 0 |  |  | 0 | 0 | 0
 |  |  |  |  |  |  |  |  |  | 0 | 0 | 0 |  |  | 0 | 0 | 0 |  |  | 0 | 0 | 0 |  |  | 0 | 0 | 0 |  |  | 0 | 0 | 0 |  |  | 0 | 0 | 0
 |  |  |  |  |  |  |  |  |  | 0 | 0 | 0 |  |  | 0 | 0 | 0 |  |  | 0 | 0 | 0 |  |  | 0 | 0 | 0 |  |  | 0 | 0 | 0 |  |  | 0 | 0 | 0
 |  |  |  |  |  |  |  |  |  | 0 | 0 | 0 |  |  | 0 | 0 | 0 |  |  | 0 | 0 | 0 |  |  | 0 | 0 | 0 |  |  | 0 | 0 | 0 |  |  | 0 | 0 | 0
 |  |  |  |  |  |  |  |  |  | 0 | 0 | 0 |  |  | 0 | 0 | 0 |  |  | 0 | 0 | 0 |  |  | 0 | 0 | 0 |  |  | 0 | 0 | 0 |  |  | 0 | 0 | 0
 |  |  |  |  |  |  |  |  |  | 0 | 0 | 0 |  |  | 0 | 0 | 0 |  |  | 0 | 0 | 0 |  |  | 0 | 0 | 0 |  |  | 0 | 0 | 0 |  |  | 0 | 0 | 0
 |  |  |  |  |  |  |  |  |  | 0 | 0 | 0 |  |  | 0 | 0 | 0 |  |  | 0 | 0 | 0 |  |  | 0 | 0 | 0 |  |  | 0 | 0 | 0 |  |  | 0 | 0 | 0
 |  |  |  |  |  |  |  |  |  | 0 | 0 | 0 |  |  | 0 | 0 | 0 |  |  | 0 | 0 | 0 |  |  | 0 | 0 | 0 |  |  | 0 | 0 | 0 |  |  | 0 | 0 | 0
 |  |  |  |  |  |  |  |  |  | 0 | 0 | 0 |  |  | 0 | 0 | 0 |  |  | 0 | 0 | 0 |  |  | 0 | 0 | 0 |  |  | 0 | 0 | 0 |  |  | 0 | 0 | 0
 |  |  |  |  |  |  |  |  |  | 0 | 0 | 0 |  |  | 0 | 0 | 0 |  |  | 0 | 0 | 0 |  |  | 0 | 0 | 0 |  |  | 0 | 0 | 0 |  |  | 0 | 0 | 0
 |  |  |  |  |  |  |  |  |  | 0 | 0 | 0 |  |  | 0 | 0 | 0 |  |  | 0 | 0 | 0 |  |  | 0 | 0 | 0 |  |  | 0 | 0 | 0 |  |  | 0 | 0 | 0
 |  |  |  |  |  |  |  |  |  | 0 | 0 | 0 |  |  | 0 | 0 | 0 |  |  | 0 | 0 | 0 |  |  | 0 | 0 | 0 |  |  | 0 | 0 | 0 |  |  | 0 | 0 | 0
 |  |  |  |  |  |  |  |  |  | 0 | 0 | 0 |  |  | 0 | 0 | 0 |  |  | 0 | 0 | 0 |  |  | 0 | 0 | 0 |  |  | 0 | 0 | 0 |  |  | 0 | 0 | 0
 |  |  |  |  |  |  |  |  |  | 0 | 0 | 0 |  |  | 0 | 0 | 0 |  |  | 0 | 0 | 0 |  |  | 0 | 0 | 0 |  |  | 0 | 0 | 0 |  |  | 0 | 0 | 0
 |  |  |  |  |  |  |  |  |  | 0 | 0 | 0 |  |  | 0 | 0 | 0 |  |  | 0 | 0 | 0 |  |  | 0 | 0 | 0 |  |  | 0 | 0 | 0 |  |  | 0 | 0 | 0
 |  |  |  |  |  |  |  |  |  | 0 | 0 | 0 |  |  | 0 | 0 | 0 |  |  | 0 | 0 | 0 |  |  | 0 | 0 | 0 |  |  | 0 | 0 | 0 |  |  | 0 | 0 | 0
 |  |  |  |  |  |  |  |  |  | 0 | 0 | 0 |  |  | 0 | 0 | 0 |  |  | 0 | 0 | 0 |  |  | 0 | 0 | 0 |  |  | 0 | 0 | 0 |  |  | 0 | 0 | 0

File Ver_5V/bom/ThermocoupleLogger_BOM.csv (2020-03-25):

Component | Description | Part | References | Value | Footprint | Quantity Per PCB | Datasheet | Part# | Placement | Package_ID | Characteristics
1 | - | Battery-device | BT1 | 9V | JST_XH_B02B-XH-A_02x2.50mm_Straight | 1 | /Users/johnpateman/Dropbox/Components/Datasheets/connectors/eXH.pdf | B2B-XH-A | - | - | -
2 | - | Battery_Cell-device | BT2 | Battery | Keystone_103_1x20mm-CoinCell | 1 |  | KEYSTONE 103 | - | - | -
3 | - | C_Small-device | C5 C6 C7 C8 C9 C10 C11 C12 C13 | 10nF | C_0805 | 9 |  | - | - | - | X7R -
4 | - | CP_Small | C4 | 10uF | CP_Elec_4x5.4 | 1 |  | EEEFK1C100R | - | - | -
5 | - | C_Small-device | C16 C17 | 12pF | C_0805 | 2 |  | - | - | - | -
6 | - | C_Small-device | C14 C15 | 18pF | C_0805 | 2 |  | - | - | - | -
7 | - | C_Small | C3 | 1uF | C_0805 | 1 |  | - | - | - | -
8 | - | C_Small-device | C1 | 470nF | C_0805 | 1 |  | - | - | - | X7R
9 | - | CP_Small-device | C2 | 47uF | CP_Elec_5x5.3 | 1 |  | EEEFK1C470UR | - | - | -
10 | - | 1N4007-diode | D1 | 1N4007 | D_DO-41_SOD81_P10.16mm_Horizontal | 1 |  | 1N4007 | +V1 -V2 | - | -
11 | - | D_Zener_Small_ALT-device | D3 D4 D5 | 3.3V | D_SOD-123 | 3 | /Users/johnpateman/Dropbox/Components/Datasheets/Diodes/BZT52C3V3-7-F.pdf | BZT52C3V3-7-F | - | - | -
12 | - | D_Schottky_Small-device | D2 | 9V | D_SOD-323 | 1 | - | BAT60JFILM | +V2 -V1 | - | -
13 | - | Barrel_Jack-RESCUE-ThermocoupleLogger | J1 | Barrel_Jack | BARREL_JACK | 1 |  | MJ-179PH | - | - | -
14 | - | Ferrite_Bead_Small | L1 L2 L3 L4 L5 L6 L7 L8 L9 L10 L11 L12 L13 L14 L15 L16 | 150 | L_0805_2012Metric | 16 | /Users/johnpateman/Dropbox/Components/Datasheets/ferrite/tdk/fcd7f82f19a65440ec3af90a524c5a0e.pdf | MPZ2012S101A | - | - | -
15 | - | Conn_02x03_Odd_Even | P1 | CONN_02X03 | Pin_Header_Straight_2x03_Pitch2.54mm | 1 |  | 75869-131LF | - | - | -
16 | - | Conn_01x04 | P2 | Conn_01x04 | JST_XH_B04B-XH-A_1x04_P2.50mm_Vertical | 1 | ~ | B4B-XH-A | - | - | -
17 | - | BD139-RESCUE-ThermocoupleLogger | Q2 | BD139 | TO-126_Vertical | 1 |  | BD139 | - | - | -
18 | - | BS250-RESCUE-ThermocoupleLogger | Q1 | BS250 | TSOT-23 | 1 |  | BS250FTA | +V2 -V1 | - | -
19 | - | R-device | R1 | 10K | R_0805 | 1 | /Users/johnpateman/Dropbox/Components/Datasheets/resistor_smd/yageo___phycomp/996acc683d858e9d3728cdae3cb41e84.pdf | - | +V2 -V1 | - | -
20 | - | R_Small-device | R2 R8 | 10K | R_0805 | 2 | /Users/johnpateman/Dropbox/Components/Datasheets/resistor_smd/yageo___phycomp/996acc683d858e9d3728cdae3cb41e84.pdf | - | - | - | -
21 | - | R_Small-device | R3 R4 R5 | 220R | R_0805 | 3 | /Users/johnpateman/Dropbox/Components/Datasheets/resistor_smd/yageo___phycomp/996acc683d858e9d3728cdae3cb41e84.pdf | - | - | - | -
22 | - | R-device | R6 R7 | 5.1K | R_0805 | 2 | /Users/johnpateman/Dropbox/Components/Datasheets/resistor_smd/yageo___phycomp/996acc683d858e9d3728cdae3cb41e84.pdf | - | - | - | -
23 | - | SW_Push-RESCUE-ThermocoupleLogger | SW1 SW2 | SW_Push | SW_PUSH_6mm_h5mm | 2 |  | SKHHAJA010 | - | - | -
24 | - | 7805-jp_components | U2 | 7805 | TO-220_Vertical | 1 |  | LM7805 | - | - | -
25 | - | AD595-jp_components | U13 | AD595 | DIP-14_W7.62mm | 1 | file:///Users/johnpateman/Dropbox/Components/Datasheets/Temperature%20measurement/AD594_595.pdf | AD595CQ | - | CERDIP-14 | -
26 | - | ADG407-jp_components | U11 | ADG407 | DIP-28_W15.24mm | 1 |  | ADG407 | - | PDIP-28_Wide | -
27 | - | ATMEGA328P-PU-atmel | U14 | ATMEGA328P-PU | DIP-28_W7.62mm | 1 | /Users/johnpateman/Dropbox/Components/Datasheets/microcontroller/atmel/atmega168pa-pu.pdf | ATMEGA328P-PU | - | DIP-28 | -
28 | - | DS1307Z+-jp_components | U15 | DS1307+ | SOIC-8_3.9x4.9mm_Pitch1.27mm | 1 | https://datasheets.maximintegrated.com/en/ds/DS1307.pdf | DS1307ZN+ | - | - | -
29 | - | I2C_20x4_DISPLAY-jp_components | U12 | I2C_20x4_DISPLAY | JST_XH_B06B-XH-A_06x2.50mm_Straight | 1 |  | B6B-XH-A | - | - | -
30 | - | LM3940-jp_components | U1 | LM3940 | SOT-223 | 1 | /Users/johnpateman/Dropbox/Components/Datasheets/Regulators/lm3940.pdf | LM3940IMP-3.3 | - | - | -
31 | - | TC_Connector-jp_components | U3 U4 U5 U6 U7 U8 U9 U10 | TC_Connector | JST_XH_B02B-XH-A_02x2.50mm_Straight | 8 | /Users/johnpateman/Dropbox/Components/Datasheets/connectors/eXH.pdf | B2B-XH-A | - | - | -
32 | - | SD_ebay-uSD-push_push_SMD-RESCUE-ThermocoupleLogger-ThermocoupleLogger-rescue | XS1 | SD_ebay-uSD-push/push_SMD | Conn_uSDcard | 1 | /Users/johnpateman/Dropbox/Components/Datasheets/SD_Card/5429_b1.pdf | SD_Card[uSD] | - | - | -
33 | 16MHz Vertical crystal | Crystal-device | Y1 | 16MHz | Crystal_HC49-U_Vertical | 1 |  | FOXSLF-160-20 | - | - | -
34 | - | Crystal-device | Y2 | 32.768kHz | Crystal_Round_d3.0mm_Vertical | 1 |  | AB26T-32.768KHZ | - | - | -
Component Groups: | 34
Component Count: | 73
Fitted Components: | 73
Number of PCBs: | 1
Total components: | 73
Schematic Version: | 1.1
Schematic Date: | 2017-02-11
BoM Date: | Thursday, 29 November 2018 at 19:38:18
Schematic Source: | /Users/johnpateman/EDA_Workspace/Projects/Thermocouple_datalogger/Ver_5V/ThermocoupleLogger.sch
KiCad Version: | Eeschema (5.0.1-3-g963ef8bb5)

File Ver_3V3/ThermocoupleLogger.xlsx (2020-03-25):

Prj: | 8-Channel Thermocouple Datalogger [3V3] |  |  |  |  | Board Qty: | 100
Co.: | JP Enterprises |  |  |  |  | Unit Cost: | £0.00
Prj date: | Saturday, 01 December 2018 at 09:49:37 |  |  |  |  | Total Cost: | £0.00 |  |  |  | £0.00 | 0 |  |  |  | £0.00 | 0 |  |  |  | £0.00 | 0 |  |  |  | £0.00 | 0 |  |  |  | £0.00 | 0
$ date: | 2019-06-05 16:52:04
Global Part Info |  |  |  |  |  |  |  | Digi-Key |  |  |  |  | Farnell |  |  |  |  | Mouser |  |  |  |  | Newark |  |  |  |  | Rs Components
Refs | Value | Desc | Footprint | Manf# | Qty | Unit$ | Ext$ | Avail | Purch | Unit$ | Ext$ | Cat# | Avail | Purch | Unit$ | Ext$ | Cat# | Avail | Purch | Unit$ | Ext$ | Cat# | Avail | Purch | Unit$ | Ext$ | Cat# | Avail | Purch | Unit$ | Ext$ | Cat#
BT1 | Battery | - | Connector_JST:JST_XH_B02B-XH-A_1x02_P2.50mm_Vertical | B2B-XH-A(LF)(SN) (http://datasheet.octopart.com/B2B-XH-A%28LF%29%28SN%29-JST-datasheet-63094.pdf) | 0 | £0.00 | £0.00 | 185307 |  | £0.00 | £0.00 | 455-2247-ND (https://octopart.com/click/track?ak=&sig=027bc86&sid=459&ppid=7424860&vpid=131671947&ct=offers) | 283222 |  |  |  | 1516276 (https://octopart.com/click/track?ak=&sig=0a2914a&sid=819&ppid=7753615&vpid=138964144&ct=offers) |  |  |  |  |  | 2317 |  | £0.00 | £0.00 | 73M9415 (https://octopart.com/click/track?ak=&sig=08a754e&sid=2402&ppid=7753615&vpid=11763346&ct=offers) | 8 |  |  |  | 1667312 (https://octopart.com/click/track?ak=&sig=05299bf&sid=10022&ppid=7424860&vpid=501096087&ct=offers)
BT2 | 3V [CR2032] | - | Battery_Holders:Keystone_106_1x20mm-CoinCell | KEYSTONE 103 | 0 | £0.00 | £0.00
C1,C2 | 100uF | - | Capacitors_SMD:CP_Elec_5x5.3 | EEEFT1C101AR (http://datasheet.octopart.com/EEEFT1C101AR-Panasonic-datasheet-10550162.pdf) | 0 | £0.00 | £0.00 | NonStk |  | £0.00 | £0.00 | P15086TR-ND (https://octopart.com/click/track?c=1&ak=&sig=0e7c1ab&sid=459&ppid=21274271&vpid=44783099&ct=offers) | 15300 |  |  |  | 2065969 (https://octopart.com/click/track?ak=&sig=0940e29&sid=11744&ppid=21274271&vpid=132561126&ct=offers) | 12308 |  | £0.00 | £0.00 | 667EEEFT1C101AR (https://octopart.com/click/track?ak=&sig=0cce168&sid=2401&ppid=21274271&vpid=46107577&ct=offers) | 592 |  | £0.00 | £0.00 | 73T9156 (https://octopart.com/click/track?ak=&sig=0ad8308&sid=2402&ppid=21274271&vpid=64490256&ct=offers) | 29970 |  |  |  | 7472499P (https://octopart.com/click/track?ak=&sig=0ad9d4a&sid=10022&ppid=21274271&vpid=437552747&ct=offers)
C3,C16-C18,C20-C22 | 100nF | - | Capacitors_SMD:C_0805 | - | 0 | £0.00 | £0.00
C4 | 10uF | - | Capacitors_SMD:C_0805 | - | 0 | £0.00 | £0.00
C5 | 1uF | - | Capacitors_SMD:C_0805 | - | 0 | £0.00 | £0.00
C6-C15,C19 | 10nF | - | Capacitors_SMD:C_0805 | - | 0 | £0.00 | £0.00
CON1 | SD_Card | - | JP_Connectors:Conn_uSDcard | SD_Card[uSD] | 0 | £0.00 | £0.00
D1 | LED_Dual_ACA | - | LEDs:LED_D3.0mm-3 | L-93WEGW (http://datasheet.octopart.com/L-93WEGW-Kingbright-datasheet-32036393.pdf) | 0 | £0.00 | £0.00 |  |  |  |  |  | NonStk |  |  |  | 637210 (https://octopart.com/click/track?c=1&ak=&sig=03ee0bb&sid=11744&ppid=871829&vpid=237135429&ct=offers) |  |  |  |  |  | 32 |  | £0.00 | £0.00 | 17M9085 (https://octopart.com/click/track?ak=&sig=01dae4e&sid=2402&ppid=871829&vpid=6684056&ct=offers) | 7577 |  |  |  | 2285685 (https://octopart.com/click/track?ak=&sig=00cc2f5&sid=10022&ppid=871829&vpid=199042187&ct=offers)
D2,D3 | 1N4448W-7-F | - | Diodes_SMD:D_SOD-123 | 1N4448W-7-F (http://datasheet.octopart.com/1N4448W-7-F-Diodes-Inc.-datasheet-8326324.pdf) | 0 | £0.00 | £0.00 | 177000 |  | £0.00 | £0.00 | 1N4448W-FDITR-ND (https://octopart.com/click/track?ak=&sig=03507c0&sid=459&ppid=322269&vpid=1627828&ct=offers) | NonStk |  |  |  | 1843738RL (https://octopart.com/click/track?c=1&ak=&sig=0653bb4&sid=11744&ppid=322269&vpid=132236626&ct=offers) | 184322 |  | £0.00 | £0.00 | 6211N4448WF (https://octopart.com/click/track?ak=&sig=0d75d04&sid=2401&ppid=322269&vpid=37598398&ct=offers) | 3821 |  | £0.00 | £0.00 | 12T2306 (https://octopart.com/click/track?ak=&sig=019c4f1&sid=2402&ppid=322269&vpid=33281002&ct=offers) | 2400 |  |  |  | 7384730 (https://octopart.com/click/track?ak=&sig=06c8b89&sid=10022&ppid=322269&vpid=199007027&ct=offers)
IC1 | ATMEGA328-P | - | Housings_QFP:TQFP-32_7x7mm_Pitch0.8mm | ATMEGA328P-AU (http://datasheet.octopart.com/ATMEGA328P-AU-Microchip-datasheet-130027646.pdf) | 0 | £0.00 | £0.00 | 3949 |  | £0.00 | £0.00 | ATMEGA328P-AU-ND (https://octopart.com/click/track?ak=&sig=0d5999e&sid=459&ppid=77760215&vpid=408716878&ct=offers) | 815 |  |  |  | 2695348 (https://octopart.com/click/track?ak=&sig=0d1157a&sid=819&ppid=77760215&vpid=420539179&ct=offers) | 28701 |  | £0.00 | £0.00 | 556ATMEGA328PAU (https://octopart.com/click/track?ak=&sig=04d8b91&sid=2401&ppid=77760215&vpid=408978600&ct=offers) | 815 |  | £0.00 | £0.00 | 68T2935 (https://octopart.com/click/track?ak=&sig=0f1c480&sid=2402&ppid=77760215&vpid=410223178&ct=offers) | 962 |  |  |  | 1310271P (https://octopart.com/click/track?ak=&sig=01cbe3a&sid=10022&ppid=77760215&vpid=439550566&ct=offers)
J1 | FC68127 | Socket%3B Jack 3%2C 5mm%3B female%3B with two switches%3B ways%3A 4%3B THT%3B H%3A 5mm | CLIFF_FC68127 | FC68127 | 0 | £0.00 | £0.00 |  |  |  |  |  | 630 |  |  |  | 2309470 (https://octopart.com/click/track?ak=&sig=0996595&sid=819&ppid=28333216&vpid=138761329&ct=offers) |  |  |  |  |  | 370 |  | £0.00 | £0.00 | 69W8909 (https://octopart.com/click/track?ak=&sig=0125f80&sid=2402&ppid=28333216&vpid=81896271&ct=offers)
J2 | CONN_01X03 | - | Pin_Headers:Pin_Header_Straight_1x03_Pitch2.54mm | B3B-XH-A(LF)(SN) (http://datasheet.octopart.com/B3B-XH-A%28LF%29%28SN%29-JST-datasheet-63094.pdf) | 0 | £0.00 | £0.00 | 247436 |  | £0.00 | £0.00 | 455-2248-ND (https://octopart.com/click/track?ak=&sig=0dde6d6&sid=459&ppid=3990185&vpid=131671954&ct=offers) | 131490 |  |  |  | 1516277 (https://octopart.com/click/track?ak=&sig=006d8ce&sid=819&ppid=7501628&vpid=138964196&ct=offers) |  |  |  |  |  | 2679 |  | £0.00 | £0.00 | 73M9431 (https://octopart.com/click/track?ak=&sig=08aaf5d&sid=2402&ppid=7501628&vpid=11373027&ct=offers) | 7645 |  |  |  | 8201557 (https://octopart.com/click/track?ak=&sig=07cf9e5&sid=10022&ppid=3990185&vpid=202901226&ct=offers)
J3 | CONN_01X05 | - | Connector_PinHeader_2.54mm:PinHeader_1x05_P2.54mm_Vertical | B5B-XH-A(LF)(SN) (http://datasheet.octopart.com/B5B-XH-A%28LF%29%28SN%29-JST-datasheet-63094.pdf) | 0 | £0.00 | £0.00 | 147305 |  | £0.00 | £0.00 | 455-2270-ND (https://octopart.com/click/track?ak=&sig=0d59d13&sid=459&ppid=3990208&vpid=34221442&ct=offers) | 65264 |  |  |  | 1516281 (https://octopart.com/click/track?ak=&sig=0b154b9&sid=819&ppid=7501618&vpid=138964304&ct=offers) |  |  |  |  |  | 430 |  | £0.00 | £0.00 | 73M9437 (https://octopart.com/click/track?ak=&sig=04b00ab&sid=2402&ppid=7501618&vpid=11373014&ct=offers) | 3000 |  |  |  | 1724934 (https://octopart.com/click/track?c=1&ak=&sig=0fc73db&sid=10022&ppid=3990208&vpid=501096154&ct=offers)
L1-L16 | 100 Ohms 10MHz | - | Inductors_SMD:L_0805 | MPZ2012S101A (http://datasheet.octopart.com/MPZ2012S101A-TDK-datasheet-8365394.pdf) | 0 | £0.00 | £0.00 |  |  |  |  |  | NonStk |  |  |  | 1669751RL (https://octopart.com/click/track?c=1&ak=&sig=09df51f&sid=819&ppid=368225&vpid=139699747&ct=offers) | 140000 |  | £0.00 | £0.00 | 810MPZ2012S101A (https://octopart.com/click/track?ak=&sig=0ee8fe8&sid=2401&ppid=368225&vpid=37992457&ct=offers) | NonStk |  |  |  | 33P7647 (https://octopart.com/click/track?c=1&ak=&sig=085bc7a&sid=2402&ppid=368225&vpid=20241531&ct=offers)
MK1-MK4 | Mounting_Hole | - | MountingHole:MountingHole_2.7mm_M2.5_Pad_Via | - | 0 | £0.00 | £0.00
P1 | Conn_02x03_Top_Bottom | - | Connector_PinHeader_2.54mm:PinHeader_2x03_P2.54mm_Vertical | 75869-131LF (http://datasheet.octopart.com/75869-131LF-FCI-datasheet-13726216.pdf) | 0 | £0.00 | £0.00 | 30790 |  | £0.00 | £0.00 | 609-2845-ND (https://octopart.com/click/track?ak=&sig=0b6c62c&sid=459&ppid=39616169&vpid=531264160&ct=offers) |  |  |  |  |  | 11393 |  | £0.00 | £0.00 | 64975869131LF (https://octopart.com/click/track?ak=&sig=0e64419&sid=2401&ppid=39616169&vpid=115156826&ct=offers) |  |  |  |  |  | 500 |  |  |  | 1708783 (https://octopart.com/click/track?c=1&ak=&sig=012fbe8&sid=10022&ppid=39616169&vpid=501054664&ct=offers)
Q1 | MMBT3904LT1G | - | Package_TO_SOT_SMD:SOT-23 | MMBT3904LT1G (http://datasheet.octopart.com/MMBT3904LT1G-ON-Semiconductor-datasheet-618661.pdf) | 0 | £0.00 | £0.00 | 4765088 |  | £0.00 | £0.00 | MMBT3904LT1GOSDKR-ND (https://octopart.com/click/track?ak=&sig=02b059f&sid=459&ppid=3280&vpid=1935351&ct=offers) | NonStk |  |  |  | 1459100RL (https://octopart.com/click/track?c=1&ak=&sig=0ff0a7b&sid=819&ppid=3280&vpid=139246164&ct=offers) | 552960 |  | £0.00 | £0.00 | 863MMBT3904LT1G (https://octopart.com/click/track?ak=&sig=099db7c&sid=2401&ppid=3280&vpid=44862346&ct=offers) | 3133300 |  | £0.00 | £0.00 | 26AC2242 (https://octopart.com/click/track?ak=&sig=045fc1b&sid=2402&ppid=3280&vpid=480435186&ct=offers) | 6450 |  |  |  | 5450343 (https://octopart.com/click/track?ak=&sig=01b86d0&sid=10022&ppid=3280&vpid=199086378&ct=offers)
R1,R2 | 750R | - | Resistors_SMD:R_0805 | - | 0 | £0.00 | £0.00
R11 | 330R | - | Resistors_SMD:R_0805 | - | 0 | £0.00 | £0.00
R3,R4,R10 | 10k | - | Resistors_SMD:R_0805 | - | 0 | £0.00 | £0.00
R8,R9 | 4.7k | - | Resistors_SMD:R_0805 | - | 0 | £0.00 | £0.00
R5-R7 | 22k | - | Resistors_SMD:R_0805 | - | 0 | £0.00 | £0.00
SW1 | SW_SPST | - | Connector_JST:JST_XH_B02B-XH-A_1x02_P2.50mm_Vertical | B2B-XH-A(LF)(SN) (http://datasheet.octopart.com/B2B-XH-A%28LF%29%28SN%29-JST-datasheet-63094.pdf) | 0 | £0.00 | £0.00 | 185307 |  | £0.00 | £0.00 | 455-2247-ND (https://octopart.com/click/track?ak=&sig=027bc86&sid=459&ppid=7424860&vpid=131671947&ct=offers) | 283222 |  |  |  | 1516276 (https://octopart.com/click/track?ak=&sig=0a2914a&sid=819&ppid=7753615&vpid=138964144&ct=offers) |  |  |  |  |  | 2317 |  | £0.00 | £0.00 | 73M9415 (https://octopart.com/click/track?ak=&sig=08a754e&sid=2402&ppid=7753615&vpid=11763346&ct=offers) | 8 |  |  |  | 1667312 (https://octopart.com/click/track?ak=&sig=05299bf&sid=10022&ppid=7424860&vpid=501096087&ct=offers)
SW2,SW3 | SW_PUSH | - | Button_Switch_THT:SW_PUSH_6mm_H4.3mm | SKHHAJA010 (http://datasheet.octopart.com/SKHHAJA010-ALPS-datasheet-13454299.pdf) | 0 | £0.00 | £0.00 |  |  |  |  |  |  |  |  |  |  | 34428 |  | £0.00 | £0.00 | 688SKHHAJ (https://octopart.com/click/track?ak=&sig=0c923d1&sid=2401&ppid=1057589&vpid=37640328&ct=offers) |  |  |  |  |  | 4780 |  |  |  | 7581922 (https://octopart.com/click/track?ak=&sig=01ccc31&sid=10022&ppid=1057589&vpid=198976655&ct=offers)
U1 | LF50_TO252 | - | Package_TO_SOT_SMD:TO-252-3_TabPin4 | LF50ABDT-TR (http://datasheet.octopart.com/LF50ABDT-TR-STMicroelectronics-datasheet-10887915.pdf) | 0 | £0.00 | £0.00 | 14444 |  | £0.00 | £0.00 | 497-8344-1-ND (https://octopart.com/click/track?ak=&sig=06af260&sid=459&ppid=40016029&vpid=115223316&ct=offers) | NonStk |  |  |  | 2473999 (https://octopart.com/click/track?c=1&ak=&sig=04ea915&sid=11744&ppid=40016029&vpid=195292995&ct=offers) | 24330 |  | £0.00 | £0.00 | 511LF50ABDTTR (https://octopart.com/click/track?ak=&sig=085afab&sid=2401&ppid=40016029&vpid=115535258&ct=offers) | NonStk |  |  |  | 56P7944 (https://octopart.com/click/track?c=1&ak=&sig=0916ef1&sid=2402&ppid=40016029&vpid=259904740&ct=offers) | 955 |  |  |  | 6868938 (https://octopart.com/click/track?ak=&sig=0e1745e&sid=10022&ppid=40016029&vpid=199117654&ct=offers)
U12 | I2C_20x4_DISPLAY | LED Character display 20x4 I2C Bus |  | - (http://www.mantech.co.za/datasheets/products/lcd2004-i2c.pdf) | 0 | £0.00 | £0.00
U13 | DS3231 | - | Housings_SOIC:SOIC-16W_7.5x10.3mm_Pitch1.27mm | DS3231M+ (http://datasheet.octopart.com/DS3231M%2B-Maxim-Integrated-datasheet-62054857.pdf) | 0 | £0.00 | £0.00 | 42 |  | £0.00 | £0.00 | DS3231M+-ND (https://octopart.com/click/track?ak=&sig=0951b76&sid=459&ppid=44322453&vpid=118199059&ct=offers) | 335 |  |  |  | 2515405 (https://octopart.com/click/track?ak=&sig=063e6cf&sid=819&ppid=44322453&vpid=464828402&ct=offers) | 760 |  | £0.00 | £0.00 | 700DS3231M+ (https://octopart.com/click/track?ak=&sig=0e94655&sid=2401&ppid=44322453&vpid=116121165&ct=offers) | 25 |  | £0.00 | £0.00 | 73Y1622 (https://octopart.com/click/track?ak=&sig=08d23ec&sid=2402&ppid=44322453&vpid=423905310&ct=offers)
U14 | MAX31855KASA | Real Time Clock with integrated oscillator | Package_SO:SOIC-8_3.9x4.9mm_P1.27mm | MAX31855KASA (http://datasheet.octopart.com/MAX31855KASA%2B-Maxim-Integrated-datasheet-62055030.pdf) | 0 | £0.00 | £0.00 | 4865 |  | £0.00 | £0.00 | MAX31855KASA+-ND (https://octopart.com/click/track?ak=&sig=040b8c1&sid=459&ppid=44378229&vpid=115951621&ct=offers) | 1390 |  |  |  | 2515562 (https://octopart.com/click/track?ak=&sig=0e5d88c&sid=819&ppid=44378229&vpid=247810293&ct=offers) | 7418 |  | £0.00 | £0.00 | 700MAX31855KASA+ (https://octopart.com/click/track?ak=&sig=0a58e33&sid=2401&ppid=44378229&vpid=115533412&ct=offers) | 49 |  | £0.00 | £0.00 | 73Y3352 (https://octopart.com/click/track?ak=&sig=0255365&sid=2402&ppid=44378229&vpid=252533315&ct=offers) | 200 |  |  |  | 1659491 (https://octopart.com/click/track?c=1&ak=&sig=00d5840&sid=10022&ppid=44378229&vpid=501135741&ct=offers)
U2 | RT9166-33GVL | - | TO_SOT_Packages_SMD:SOT-23 | RT9166-33GVL (http://datasheet.octopart.com/RT9166-33GVL-Richtek-datasheet-21405076.pdf) | 0 | £0.00 | £0.00 | NonStk |  | £0.00 | £0.00 | RT9166-33GVL-ND (https://octopart.com/click/track?c=1&ak=&sig=01aca09&sid=459&ppid=19674177&vpid=36257747&ct=offers) | 272 |  |  |  | 2363085 (https://octopart.com/click/track?ak=&sig=0ae7b15&sid=819&ppid=19674177&vpid=139418247&ct=offers) |  |  |  |  |  | 420 |  | £0.00 | £0.00 | 02AC3858 (https://octopart.com/click/track?ak=&sig=0c8fc44&sid=2402&ppid=19674177&vpid=314850526&ct=offers)
U3,U5-U11 | TC_Connector | - | Connector_JST:JST_XH_B02B-XH-A_1x02_P2.50mm_Vertical | B2B-XH-A(LF)(SN) (http://datasheet.octopart.com/B2B-XH-A%28LF%29%28SN%29-JST-datasheet-63094.pdf) | 0 | £0.00 | £0.00 | 185307 |  | £0.00 | £0.00 | 455-2247-ND (https://octopart.com/click/track?ak=&sig=027bc86&sid=459&ppid=7424860&vpid=131671947&ct=offers) | 283222 |  |  |  | 1516276 (https://octopart.com/click/track?ak=&sig=0a2914a&sid=819&ppid=7753615&vpid=138964144&ct=offers) |  |  |  |  |  | 2317 |  | £0.00 | £0.00 | 73M9415 (https://octopart.com/click/track?ak=&sig=08a754e&sid=2402&ppid=7753615&vpid=11763346&ct=offers) | 8 |  |  |  | 1667312 (https://octopart.com/click/track?ak=&sig=05299bf&sid=10022&ppid=7424860&vpid=501096087&ct=offers)
U4 | ADG407BPZ | - | Housings_LCC:PLCC-28 | ADG407BPZ (http://www.analog.com/media/en/technical-documentation/data-sheets/ADG406_407_426.pdf) | 0 | £0.00 | £0.00 | 614 |  | £0.00 | £0.00 | ADG407BPZ-ND (https://octopart.com/click/track?ak=&sig=06a968c&sid=459&ppid=80741&vpid=1633322&ct=offers) | NonStk |  |  |  | 2460590 (https://octopart.com/click/track?c=1&ak=&sig=048ebf1&sid=819&ppid=80741&vpid=202967413&ct=offers) | 583 |  | £0.00 | £0.00 | 584ADG407BPZ (https://octopart.com/click/track?ak=&sig=01f57f4&sid=2401&ppid=80741&vpid=77864500&ct=offers) | NonStk |  | £0.00 | £0.00 | 39Y2632 (https://octopart.com/click/track?c=1&ak=&sig=0463ab1&sid=2402&ppid=80741&vpid=182269899&ct=offers) | 117 |  |  |  | 9128788 (https://octopart.com/click/track?c=1&ak=&sig=01dd9a0&sid=10022&ppid=80741&vpid=265577701&ct=offers)
Y1 | Crystal_8MHz | Abracon 8MHz Crystal | Crystals:Crystal_SMD_Abracon_ABM3B-4pin_5.0x3.2mm | ABM3B-8.000MHZ-B2-T (http://datasheet.octopart.com/ABM3B-8.000MHZ-B2-T-Abracon-datasheet-12510201.pdf) | 0 | £0.00 | £0.00 | 174310 |  | £0.00 | £0.00 | 535-9720-6-ND (https://octopart.com/click/track?ak=&sig=018f07c&sid=459&ppid=12808281&vpid=34208371&ct=offers) | 486 |  |  |  | 2467818 (https://octopart.com/click/track?ak=&sig=0ba9978&sid=11744&ppid=12808281&vpid=183071785&ct=offers) | 63090 |  | £0.00 | £0.00 | 815ABM3B8.0B2T (https://octopart.com/click/track?ak=&sig=06e95d0&sid=2401&ppid=12808281&vpid=37714686&ct=offers) | NonStk |  | £0.00 | £0.00 | 40Y2011 (https://octopart.com/click/track?c=1&ak=&sig=0975381&sid=2402&ppid=12808281&vpid=294492347&ct=offers) | 130 |  |  |  | 1710644 (https://octopart.com/click/track?ak=&sig=0c362db&sid=10022&ppid=12808281&vpid=500992985&ct=offers)
KiCost® v.1.1 |  |  |  |  |  | Total Purchase: | £0.00 |  | 0 |  | £0.00 |  |  | 0 |  | £0.00 |  |  | 0 |  | £0.00 |  |  | 0 |  | £0.00 |  |  | 0 |  | £0.00
 |  |  |  |  |  |  |  |  | 0 |  |  |  |  | 0 |  |  |  |  | 0 |  |  |  |  | 0 |  |  |  |  | 0
 |  |  |  |  |  |  |  |  | 0 |  |  |  |  | 0 |  |  |  |  | 0 |  |  |  |  | 0 |  |  |  |  | 0
 |  |  |  |  |  |  |  |  | 0 |  |  |  |  | 0 |  |  |  |  | 0 |  |  |  |  | 0 |  |  |  |  | 0
 |  |  |  |  |  |  |  |  | 0 |  |  |  |  | 0 |  |  |  |  | 0 |  |  |  |  | 0 |  |  |  |  | 0
 |  |  |  |  |  |  |  |  | 0 |  |  |  |  | 0 |  |  |  |  | 0 |  |  |  |  | 0 |  |  |  |  | 0
 |  |  |  |  |  |  |  |  | 0 |  |  |  |  | 0 |  |  |  |  | 0 |  |  |  |  | 0 |  |  |  |  | 0
 |  |  |  |  |  |  |  |  | 0 |  |  |  |  | 0 |  |  |  |  | 0 |  |  |  |  | 0 |  |  |  |  | 0
 |  |  |  |  |  |  |  |  | 0 |  |  |  |  | 0 |  |  |  |  | 0 |  |  |  |  | 0 |  |  |  |  | 0
 |  |  |  |  |  |  |  |  | 0 |  |  |  |  | 0 |  |  |  |  | 0 |  |  |  |  | 0 |  |  |  |  | 0
 |  |  |  |  |  |  |  |  | 0 |  |  |  |  | 0 |  |  |  |  | 0 |  |  |  |  | 0 |  |  |  |  | 0
 |  |  |  |  |  |  |  |  | 0 |  |  |  |  | 0 |  |  |  |  | 0 |  |  |  |  | 0 |  |  |  |  | 0
 |  |  |  |  |  |  |  |  | 0 |  |  |  |  | 0 |  |  |  |  | 0 |  |  |  |  | 0 |  |  |  |  | 0
 |  |  |  |  |  |  |  |  | 0 |  |  |  |  | 0 |  |  |  |  | 0 |  |  |  |  | 0 |  |  |  |  | 0
 |  |  |  |  |  |  |  |  | 0 |  |  |  |  | 0 |  |  |  |  | 0 |  |  |  |  | 0 |  |  |  |  | 0
 |  |  |  |  |  |  |  |  | 0 |  |  |  |  | 0 |  |  |  |  | 0 |  |  |  |  | 0 |  |  |  |  | 0
 |  |  |  |  |  |  |  |  | 0 |  |  |  |  | 0 |  |  |  |  | 0 |  |  |  |  | 0 |  |  |  |  | 0
 |  |  |  |  |  |  |  |  | 0 |  |  |  |  | 0 |  |  |  |  | 0 |  |  |  |  | 0 |  |  |  |  | 0
 |  |  |  |  |  |  |  |  | 0 |  |  |  |  | 0 |  |  |  |  | 0 |  |  |  |  | 0 |  |  |  |  | 0
 |  |  |  |  |  |  |  |  | 0 |  |  |  |  | 0 |  |  |  |  | 0 |  |  |  |  | 0 |  |  |  |  | 0
 |  |  |  |  |  |  |  |  | 0 |  |  |  |  | 0 |  |  |  |  | 0 |  |  |  |  | 0 |  |  |  |  | 0
 |  |  |  |  |  |  |  |  | 0 |  |  |  |  | 0 |  |  |  |  | 0 |  |  |  |  | 0 |  |  |  |  | 0
 |  |  |  |  |  |  |  |  | 0 |  |  |  |  | 0 |  |  |  |  | 0 |  |  |  |  | 0 |  |  |  |  | 0
 |  |  |  |  |  |  |  |  | 0 |  |  |  |  | 0 |  |  |  |  | 0 |  |  |  |  | 0 |  |  |  |  | 0
 |  |  |  |  |  |  |  |  | 0 |  |  |  |  | 0 |  |  |  |  | 0 |  |  |  |  | 0 |  |  |  |  | 0
 |  |  |  |  |  |  |  |  | 0 |  |  |  |  | 0 |  |  |  |  | 0 |  |  |  |  | 0 |  |  |  |  | 0
 |  |  |  |  |  |  |  |  | 0 |  |  |  |  | 0 |  |  |  |  | 0 |  |  |  |  | 0 |  |  |  |  | 0
 |  |  |  |  |  |  |  |  | 0 |  |  |  |  | 0 |  |  |  |  | 0 |  |  |  |  | 0 |  |  |  |  | 0
 |  |  |  |  |  |  |  |  | 0 |  |  |  |  | 0 |  |  |  |  | 0 |  |  |  |  | 0 |  |  |  |  | 0
 |  |  |  |  |  |  |  |  | 0 |  |  |  |  | 0 |  |  |  |  | 0 |  |  |  |  | 0 |  |  |  |  | 0
 |  |  |  |  |  |  |  |  | 0 |  |  |  |  | 0 |  |  |  |  | 0 |  |  |  |  | 0 |  |  |  |  | 0
 |  |  |  |  |  |  |  |  | 0 |  |  |  |  | 0 |  |  |  |  | 0 |  |  |  |  | 0 |  |  |  |  | 0
 |  |  |  |  |  |  |  |  | 0 |  |  |  |  | 0 |  |  |  |  | 0 |  |  |  |  | 0 |  |  |  |  | 0
 |  |  |  |  |  |  |  |  | 0 |  |  |  |  | 0 |  |  |  |  | 0 |  |  |  |  | 0 |  |  |  |  | 0

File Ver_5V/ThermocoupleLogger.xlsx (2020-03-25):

Prj: | 8-Channel Thermocouple Datalogger |  |  |  |  |  | Board Qty: | 100
Co.: | JP Enterprises |  |  |  |  |  | Unit Cost: | £22.08
Prj date: | Thursday, 19 September 2019 at 17:57:04 |  |  |  |  |  | Total Cost: | £2208.16 |  |  |  | £2587.56 | 0 |  |  |  | £2414.01 | 0 |  |  |  | £2528.32 | 0 |  |  |  | £2141.93 | 0 |  |  |  | £2154.20 | 0
$ date: | 2019-09-20 17:33:20
Global Part Info |  |  |  |  |  |  |  |  | Digi-Key |  |  |  |  | Farnell |  |  |  |  | Mouser |  |  |  |  | Newark |  |  |  |  | Rs Components
Refs | Value | Desc | Footprint | Manf | Manf# | Qty | Unit$ | Ext$ | Avail | Purch | Unit$ | Ext$ | Cat# | Avail | Purch | Unit$ | Ext$ | Cat# | Avail | Purch | Unit$ | Ext$ | Cat# | Avail | Purch | Unit$ | Ext$ | Cat# | Avail | Purch | Unit$ | Ext$ | Cat#
BT1 | 9V | - | Connector_JST:JST_XH_B02B-XH-A_1x02_P2.50mm_Vertical |  | B2B-XH-A | 100 | £0.00 | £0.00
BT2 | Battery | - | Battery:BatteryHolder_Keystone_103_1x20mm |  | KEYSTONE 103 | 100 | £0.00 | £0.00
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

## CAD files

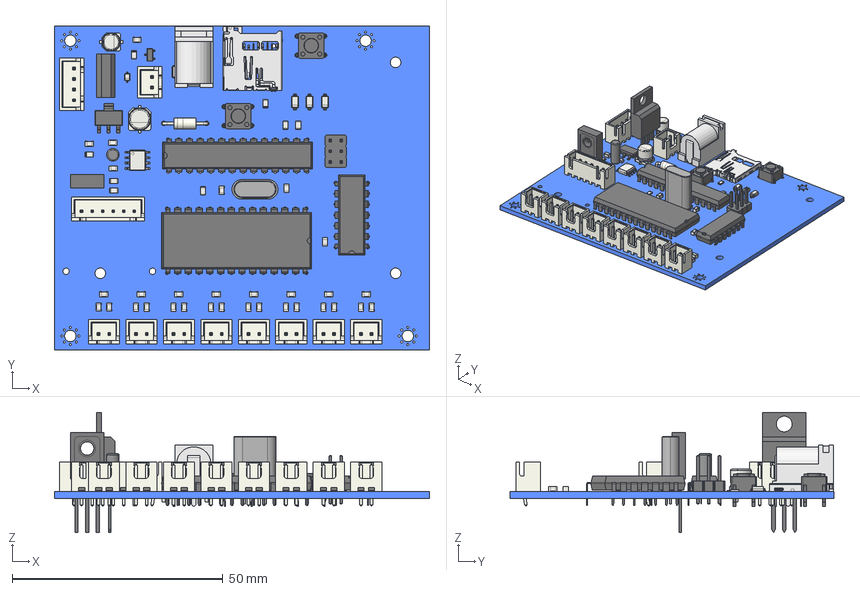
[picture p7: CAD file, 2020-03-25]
Ver_5V/Renders:STEP/ThermocoupleLogger.FCStd
88.9 x 76.8 x 28.5 mm
Pcb
CP_Elec_4x53_
CP_Elec_4x53_001
JST_B04B_XH_A_
JST_B04B_XH_A_001
L_0805_2012Metric_
L_0805_2012Metric_001
L_0805_2012Metric_002
L_0805_2012Metric_003
L_0805_2012Metric_004
L_0805_2012Metric_005
L_0805_2012Metric_006
L_0805_2012Metric_007
L_0805_2012Metric_008
L_0805_2012Metric_009
L_0805_2012Metric_010
L_0805_2012Metric_011
L_0805_2012Metric_012
L_0805_2012Metric_013
L_0805_2012Metric_014
L_0805_2012Metric_015
micro SD Card Slot_
JST_B06B_XH_A_
JST_B06B_XH_A_001
PinHeader_2x03_P254mm_Vertical_
PinHeader_2x03_P254mm_Vertical_001
DIP-14_W7.62mm_
DIP-14_W7.62mm_001
SOIC_8_39x49mm_P127mm_
SOIC_8_39x49mm_P127mm_001
R_0805_2012Metric_
R_0805_2012Metric_001
D_SOD_123_
D_SOD_123_001
TO-220-3_Vertical_
TO-220-3_Vertical_001
SOT_223_
SOT_223_001
C_0805_2012Metric_
C_0805_2012Metric_001
C_0805_2012Metric_002
C_0805_2012Metric_003
C_0805_2012Metric_004
C_0805_2012Metric_005
C_0805_2012Metric_006
C_0805_2012Metric_007
C_0805_2012Metric_008
C_0805_2012Metric_009
C_0805_2012Metric_010
C_0805_2012Metric_011
C_0805_2012Metric_012
C_0805_2012Metric_013
C_0805_2012Metric_014
C_0805_2012Metric_015
JST_B02B_XH_A_
JST_B02B_XH_A_001
JST_B02B_XH_A_002
JST_B02B_XH_A_003
JST_B02B_XH_A_004
JST_B02B_XH_A_005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

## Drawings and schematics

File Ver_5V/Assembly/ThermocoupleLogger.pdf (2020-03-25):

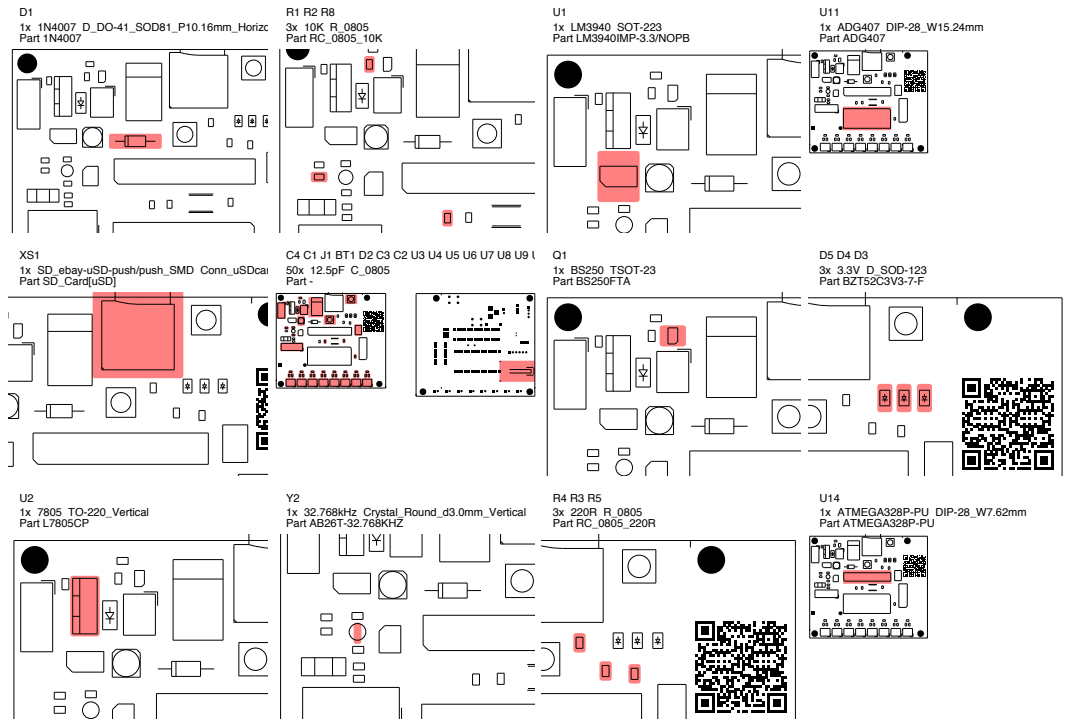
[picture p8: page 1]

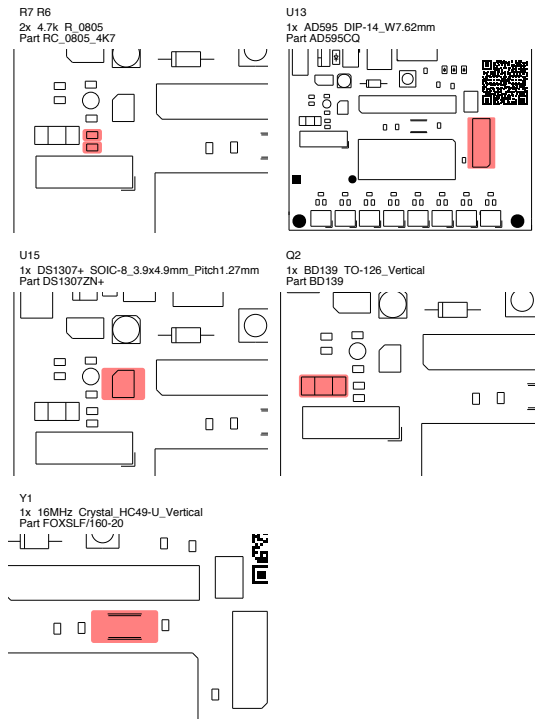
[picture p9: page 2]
R7 R6 2x 4.7k R_0805 Part RC_0805_4K7; U15 1x DS1307+ SOIC-8_3.9x4.9mm_Pitch1.27mm Part DS1307ZN+; Y1 1x 16MHz Crystal_HC49-U_Vertical Part FOXSLF/160-20; U13 1x AD595 DIP-14_W7.62mm Part AD595CQ; Q2 1x BD139 TO-126_Vertical Part BD139

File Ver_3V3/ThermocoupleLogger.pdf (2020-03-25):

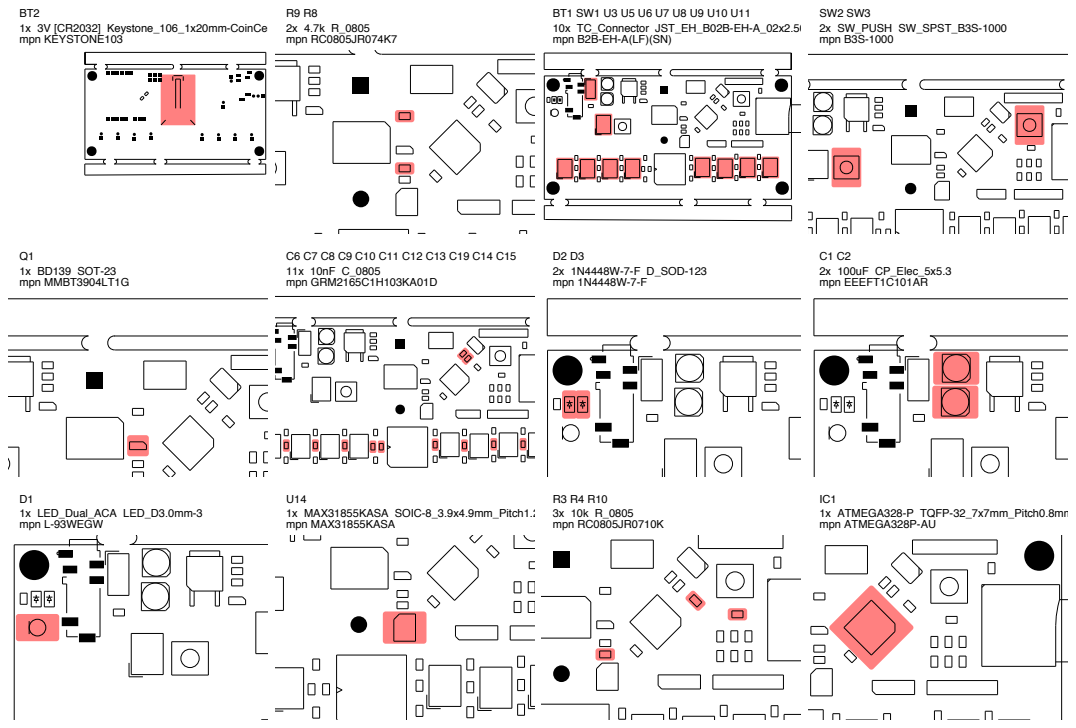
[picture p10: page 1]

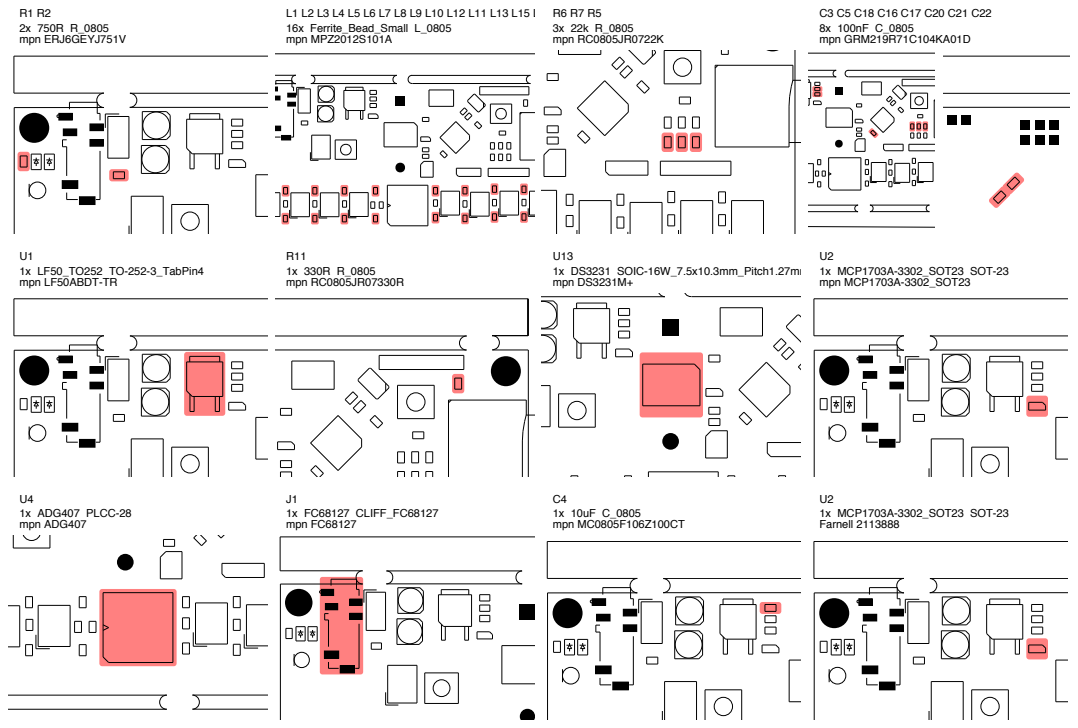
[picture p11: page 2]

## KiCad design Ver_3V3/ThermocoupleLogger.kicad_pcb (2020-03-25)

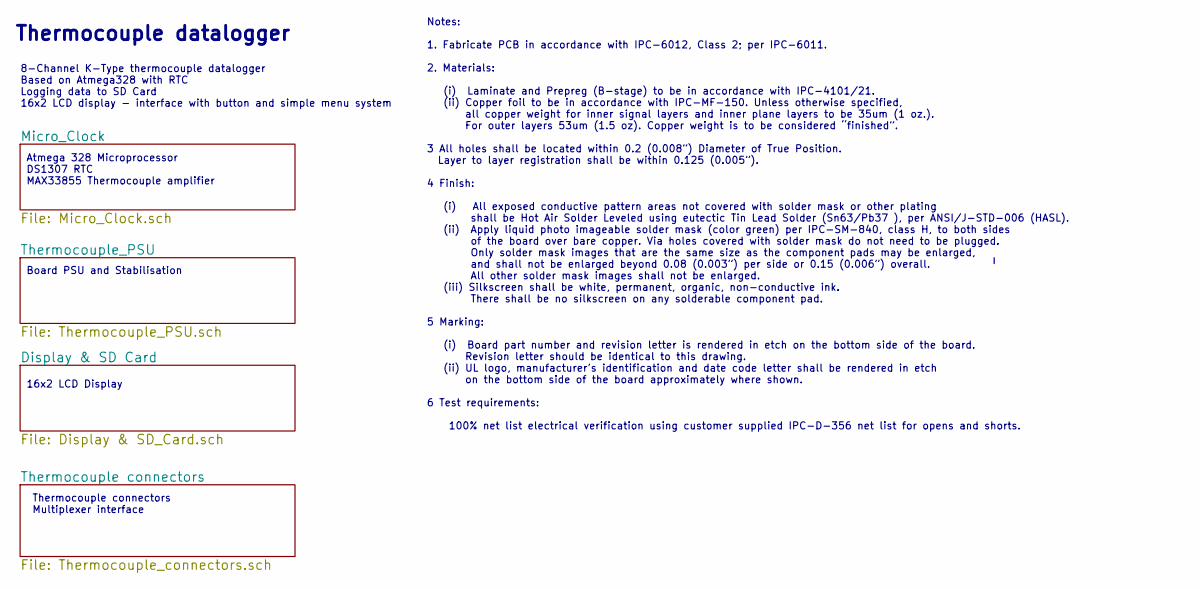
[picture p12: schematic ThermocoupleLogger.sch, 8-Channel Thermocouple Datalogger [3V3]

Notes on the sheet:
Thermocouple datalogger
8-Channel K-Type thermocouple datalogger Based on Atmega328 with RTC Logging data to SD Card 16x2 LCD display - interface with button and simple menu system
Atmega 328 Microprocessor DS1307 RTC MAX33855 Thermocouple amplifier
Board PSU and Stabilisation
Thermocouple connectors Multiplexer interface
16x2 LCD Display
Notes: 1. Fabricate PCB in accordance with IPC-6012, Class 2; per IPC-6011. 2. Materials: (i) Laminate and Prepreg (B-stage) to be in accordance with IPC-4101/21. (ii) Copper foil to be in accordance with IPC-MF-150. Unless otherwise specified, all copper weight for inner signal layers and inner pl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

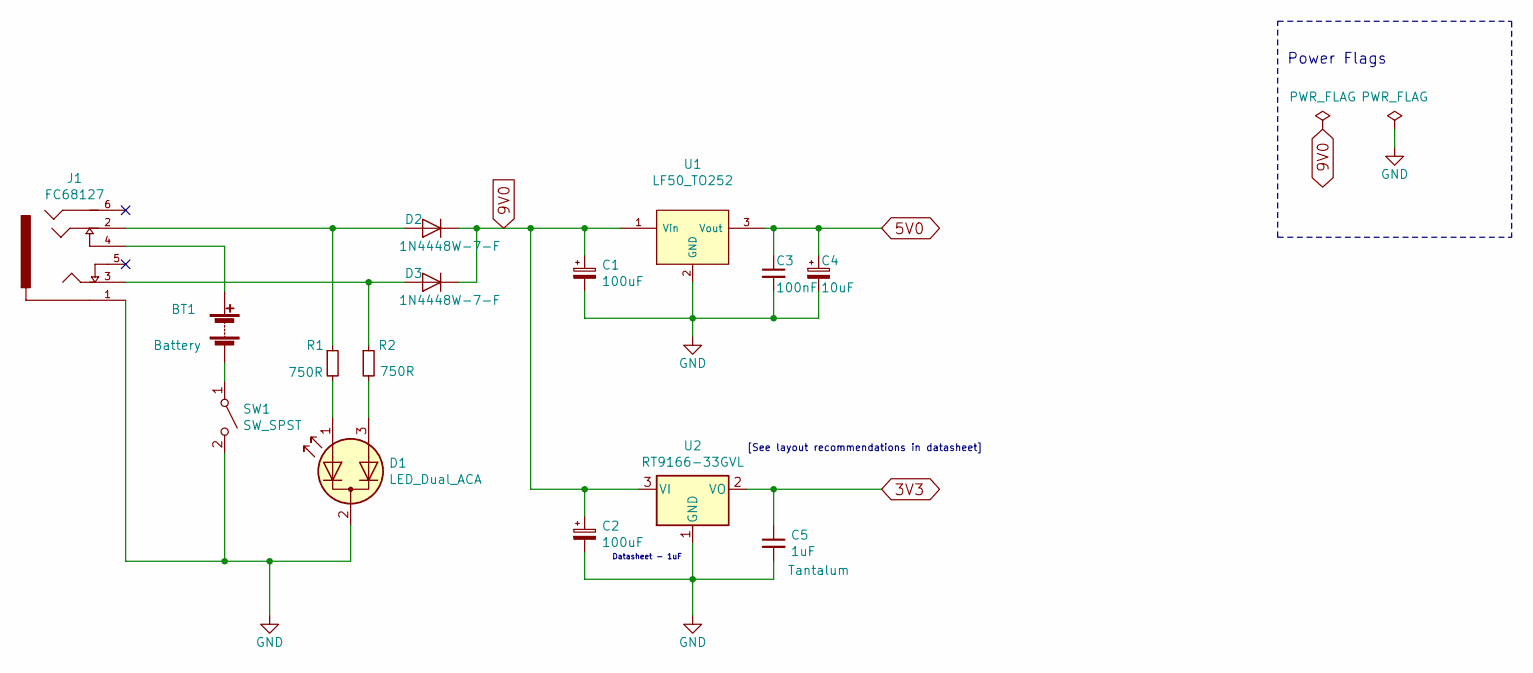
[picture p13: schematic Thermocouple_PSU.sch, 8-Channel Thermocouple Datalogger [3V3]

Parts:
BT1: Battery; JST_XH_B02B-XH-A_1x02_P2.50mm_Vertical; Part# B2B-XH-A(LF)(SN)
C1, C2: 100uF; CP_Elec_5x5.3; Part# EEEFT1C101AR
C3: 100nF; C_0805_2012Metric
C4: 10uF; CP_Elec_5x5.3
C5: 1uF; C_0805_2012Metric
D1: LED_Dual_ACA; LED_D3.0mm-3; Part# L-93WEGW
D2, D3: 1N4448W-7-F; D_SOD-123; Part# 1N4448W-7-F
J1: FC68127; CLIFF_FC68127; Part# FC68127
R1, R2: 750R; R_0805_2012Metric
SW1: SW_SPST; JST_XH_B02B-XH-A_1x02_P2.50mm_Vertical; Part# B2B-XH-A(LF)(SN)
U1: LF50_TO252; TO-252-3_TabPin4; Part# LF50ABDT-TR
U2: RT9166-33GVL; SOT-23; Part# RT9166-33GVL

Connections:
3V3: C5.1, U2.2 (VO); also elsewhere on the board
5V0: C3.1, C4.1, U1.3 (Vout); also elsewhere on the board
9V0: C1.1, C2.1, D2.1 (K), D3.1 (K), U1.1 (Vin), U2.3 (VI)
GND: C1.2, C2.2, C3.2, C4.2, C5.2, D1.2 (K), J1.1 (S), SW1.2 (B), U1.2 (GND), U2.1 (GND); also elsewhere on the board
unnamed: BT1.1 (+), J1.4 (RS)
unnamed: BT1.2 (-), SW1.1 (A)
unnamed: D1.1 (A1), R1.2
unnamed: D1.3 (A2), R2.2
unnamed: D2.2 (A), J1.2 (R), R1.1
unnamed: D3.2 (A), J1.3 (T), R2.1

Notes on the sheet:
Power Flags
[See layout recommendations in datasheet]
Datasheet - 1uF

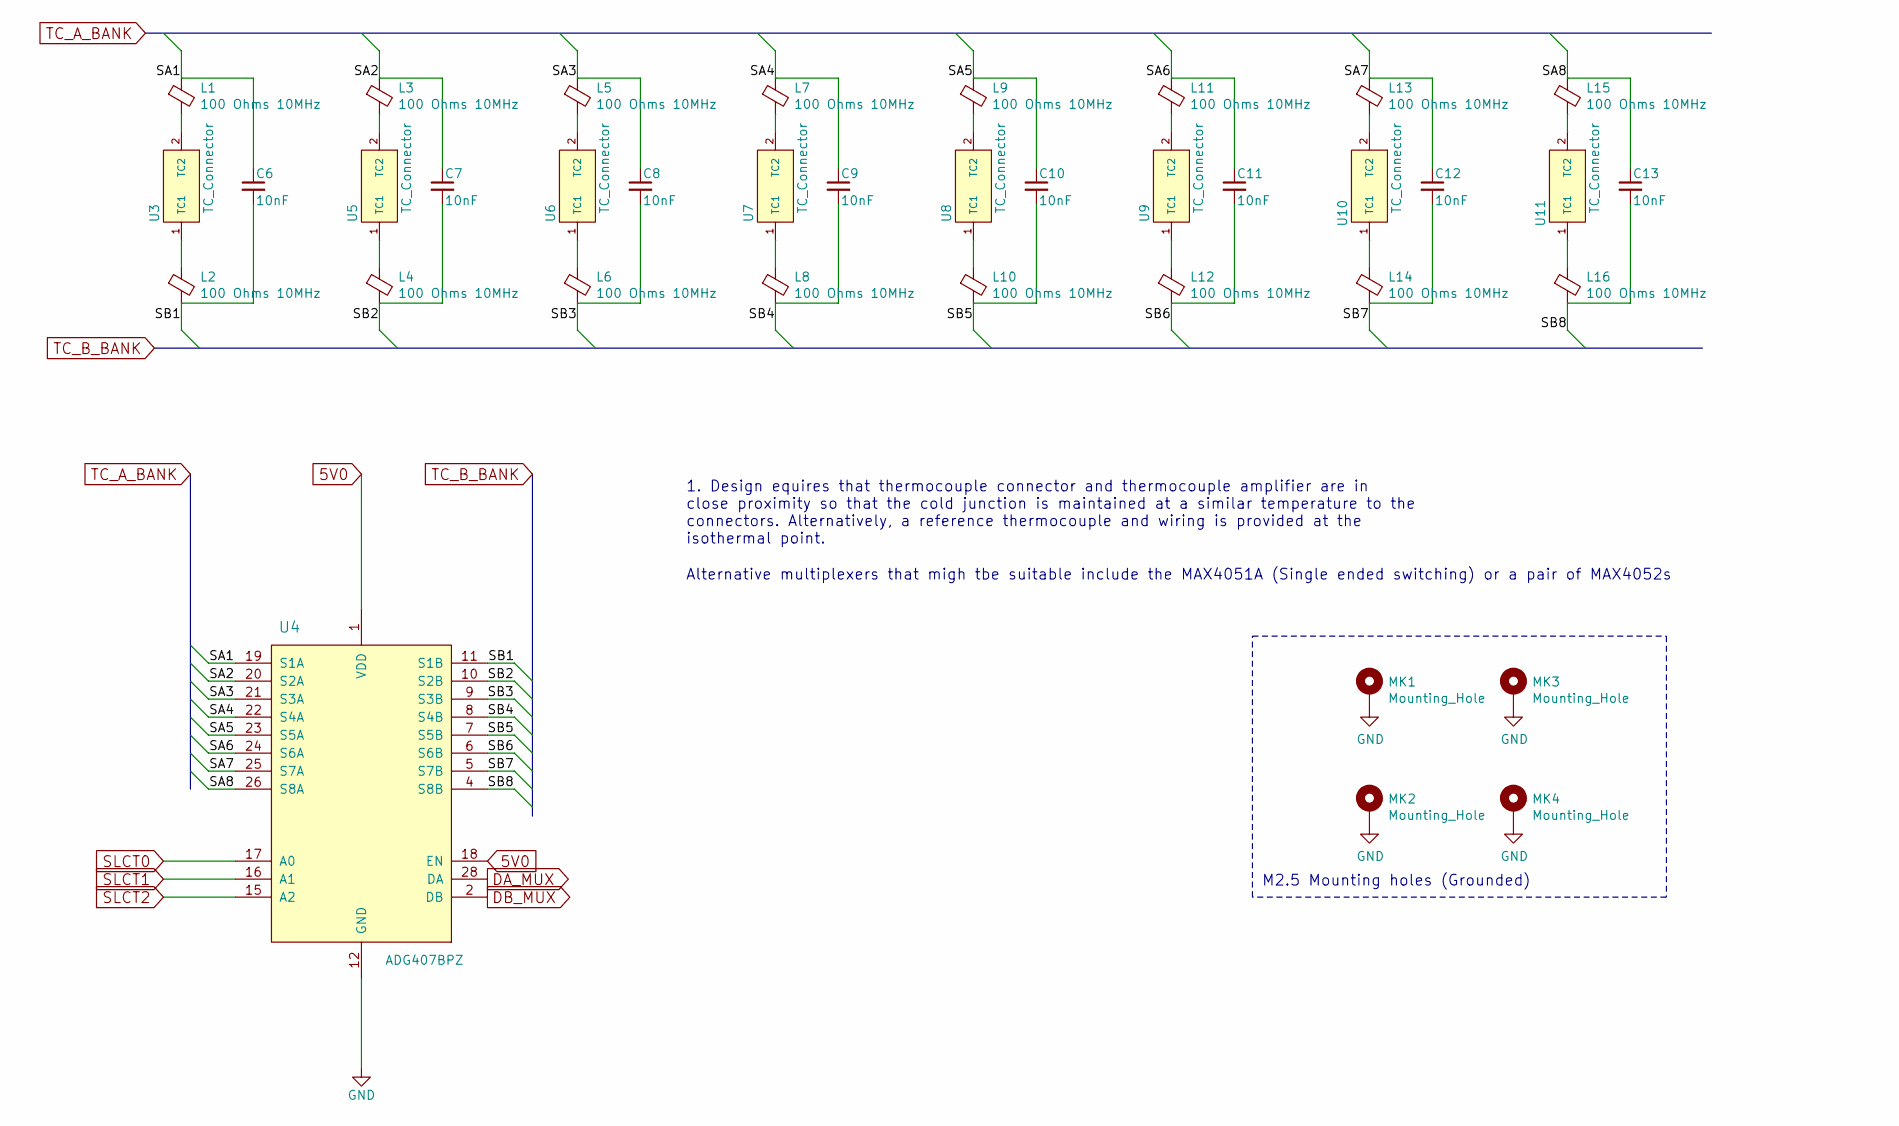
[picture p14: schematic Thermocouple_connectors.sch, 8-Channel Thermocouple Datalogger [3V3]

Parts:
C6, C7, C8, C9, C10, C11, C12, C13: 10nF; C_0805_2012Metric
L1, L2, L3, L4, L5, L6, L7, L8, L9, L10, L11, L12, L13, L14, L15, L16: 100 Ohms 10MHz; L_0805_2012Metric; Part# MPZ2012S101A
MK1, MK2, MK3, MK4: Mounting_Hole; MountingHole_2.7mm_M2.5_Pad_Via
U3, U5, U6, U7, U8, U9, U10, U11: TC_Connector; JST_XH_B02B-XH-A_1x02_P2.50mm_Vertical; Part# B2B-XH-A(LF)(SN)
U4: ADG407BPZ; PLCC-28; Part# ADG407BPZ

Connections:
5V0: U4.1 (VDD), U4.18 (EN); also elsewhere on the board
/Thermocouple connectors/SA1: C6.1, L1.1, U4.19 (S1A)
/Thermocouple connectors/SA2: C7.1, L3.1, U4.20 (S2A)
/Thermocouple connectors/SA3: C8.1, L5.1, U4.21 (S3A)
/Thermocouple connectors/SA4: C9.1, L7.1, U4.22 (S4A)
/Thermocouple connectors/SA5: C10.1, L9.1, U4.23 (S5A)
/Thermocouple connectors/SA6: C11.1, L11.1, U4.24 (S6A)
/Thermocouple connectors/SA7: C12.1, L13.1, U4.25 (S7A)
/Thermocouple connectors/SA8: C13.1, L15.1, U4.26 (S8A)
/Thermocouple connectors/SB1: C6.2, L2.2, U4.11 (S1B)
/Thermocouple connectors/SB2: C7.2, L4.2, U4.10 (S2B)
/Thermocouple connectors/SB3: C8.2, L6.2, U4.9 (S3B)
/Thermocouple connectors/SB4: C9.2, L8.2, U4.8 (S4B)
/Thermocouple connectors/SB5: C10.2, L10.2, U4.7 (S5B)
/Thermocouple connectors/SB6: C11.2, L12.2, U4.6 (S6B)
/Thermocouple connectors/SB7: C12.2, L14.2, U4.5 (S7B)
/Thermocouple connectors/SB8: C13.2, L16.2, U4.4 (S8B)
DA_MUX: U4.28 (DA); also elsewhere on the board
DB_MUX: U4.2 (DB); also elsewhere on the board
GND: MK1.1, MK2.1, MK3.1, MK4.1, U4.12 (GND); also elsewhere on the board
unnamed: L1.2, U3.2 (TC2)
unnamed: L2.1, U3.1 (TC1)
unnamed: L3.2, U5.2 (TC2)
unnamed: L4.1, U5.1 (TC1)
unnamed: L5.2, U6.2 (TC2)
unnamed: L6.1, U6.1 (TC1)
unnamed: L7.2, U7.2 (TC2)
unnamed: L8.1, U7.1 (TC1)
unnamed: L9.2, U8.2 (TC2)
unnamed: L10.1, U8.1 (TC1)
unnamed: L11.2, U9.2 (TC2)
unnamed: L12.1, U9.1 (TC1)
unnamed: L13.2, U10.2 (TC2)
unnamed: L14.1, U10.1 (TC1)
unnamed: L15.2, U11.2 (TC2)
unnamed: L16.1, U11.1 (TC1)
SLCT0: U4.17 (A0); also elsewhere on the board
SLCT1: U4.16 (A1); also elsewhere on the board
SLCT2: U4.15 (A2); also elsewhere on the board

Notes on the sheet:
1. Design equires that thermocouple connector and thermocouple amplifier are in close proximity so that the cold junction is maintained at a similar temperature to the connectors. Alternatively, a reference thermocouple and wiring is provided at the isothermal point.
Alternative multiplexers that migh tbe suitable include the MAX4051A (Single ended switching) or a pair of MAX4052s
M2.5 Mounting holes (Grounded)

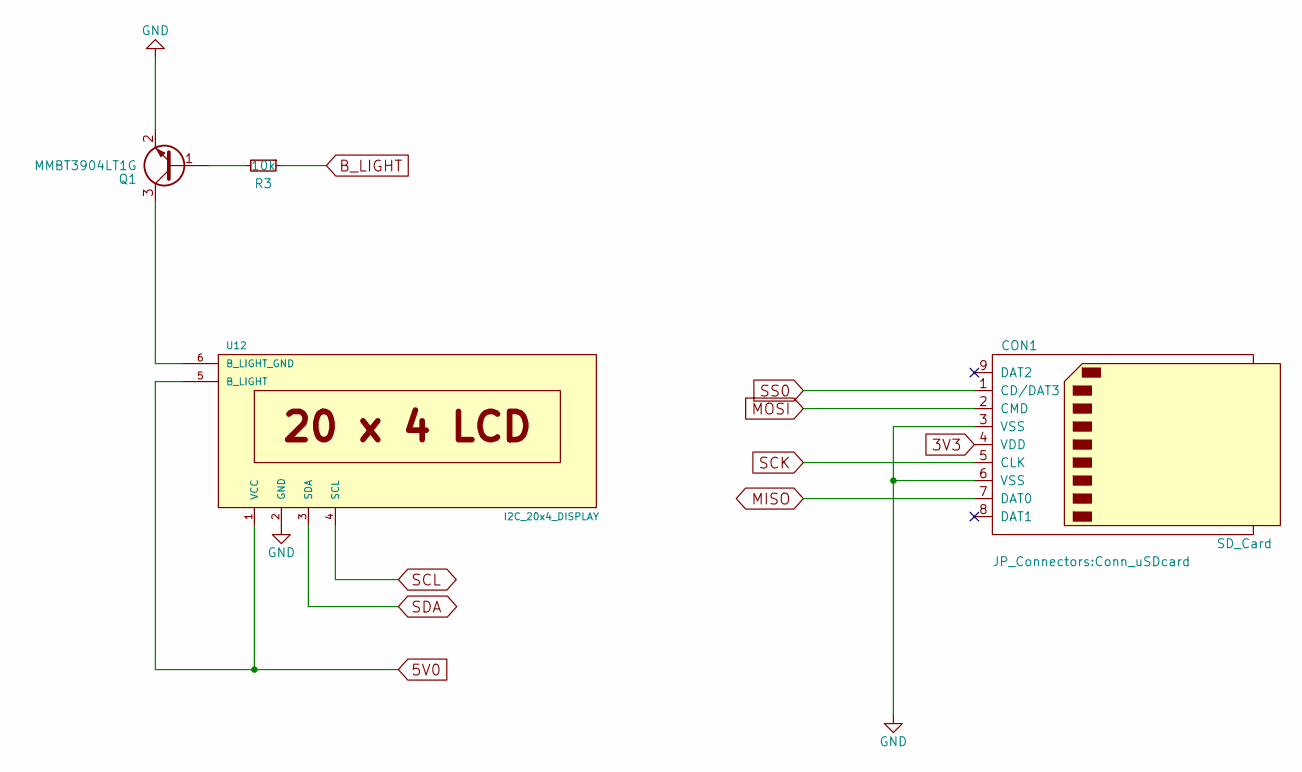
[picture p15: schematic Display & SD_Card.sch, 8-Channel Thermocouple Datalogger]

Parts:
CON1: SD_Card; Conn_uSDcard; Part# SD_Card[uSD]
Q1: MMBT3904LT1G; SOT-23; Part# MMBT3904LT1G
R3: 10k; R_0805_2012Metric
U12: I2C_20x4_DISPLAY

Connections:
3V3: CON1.4 (VDD); also elsewhere on the board
5V0: U12.1 (VCC), U12.5 (B_LIGHT); also elsewhere on the board
B_LIGHT: R3.1; also elsewhere on the board
GND: CON1.3 (VSS), CON1.6 (VSS), Q1.2 (E), U12.2 (GND); also elsewhere on the board
MISO: CON1.7 (DAT0); also elsewhere on the board
MOSI: CON1.2 (CMD); also elsewhere on the board
unnamed: Q1.1 (B), R3.2
unnamed: Q1.3 (C), U12.6 (B_LIGHT_GND)
SCK: CON1.5 (CLK); also elsewhere on the board
SCL: U12.4 (SCL); also elsewhere on the board
SDA: U12.3 (SDA); also elsewhere on the board
SS0: CON1.1 (CD/DAT3); also elsewhere on the board

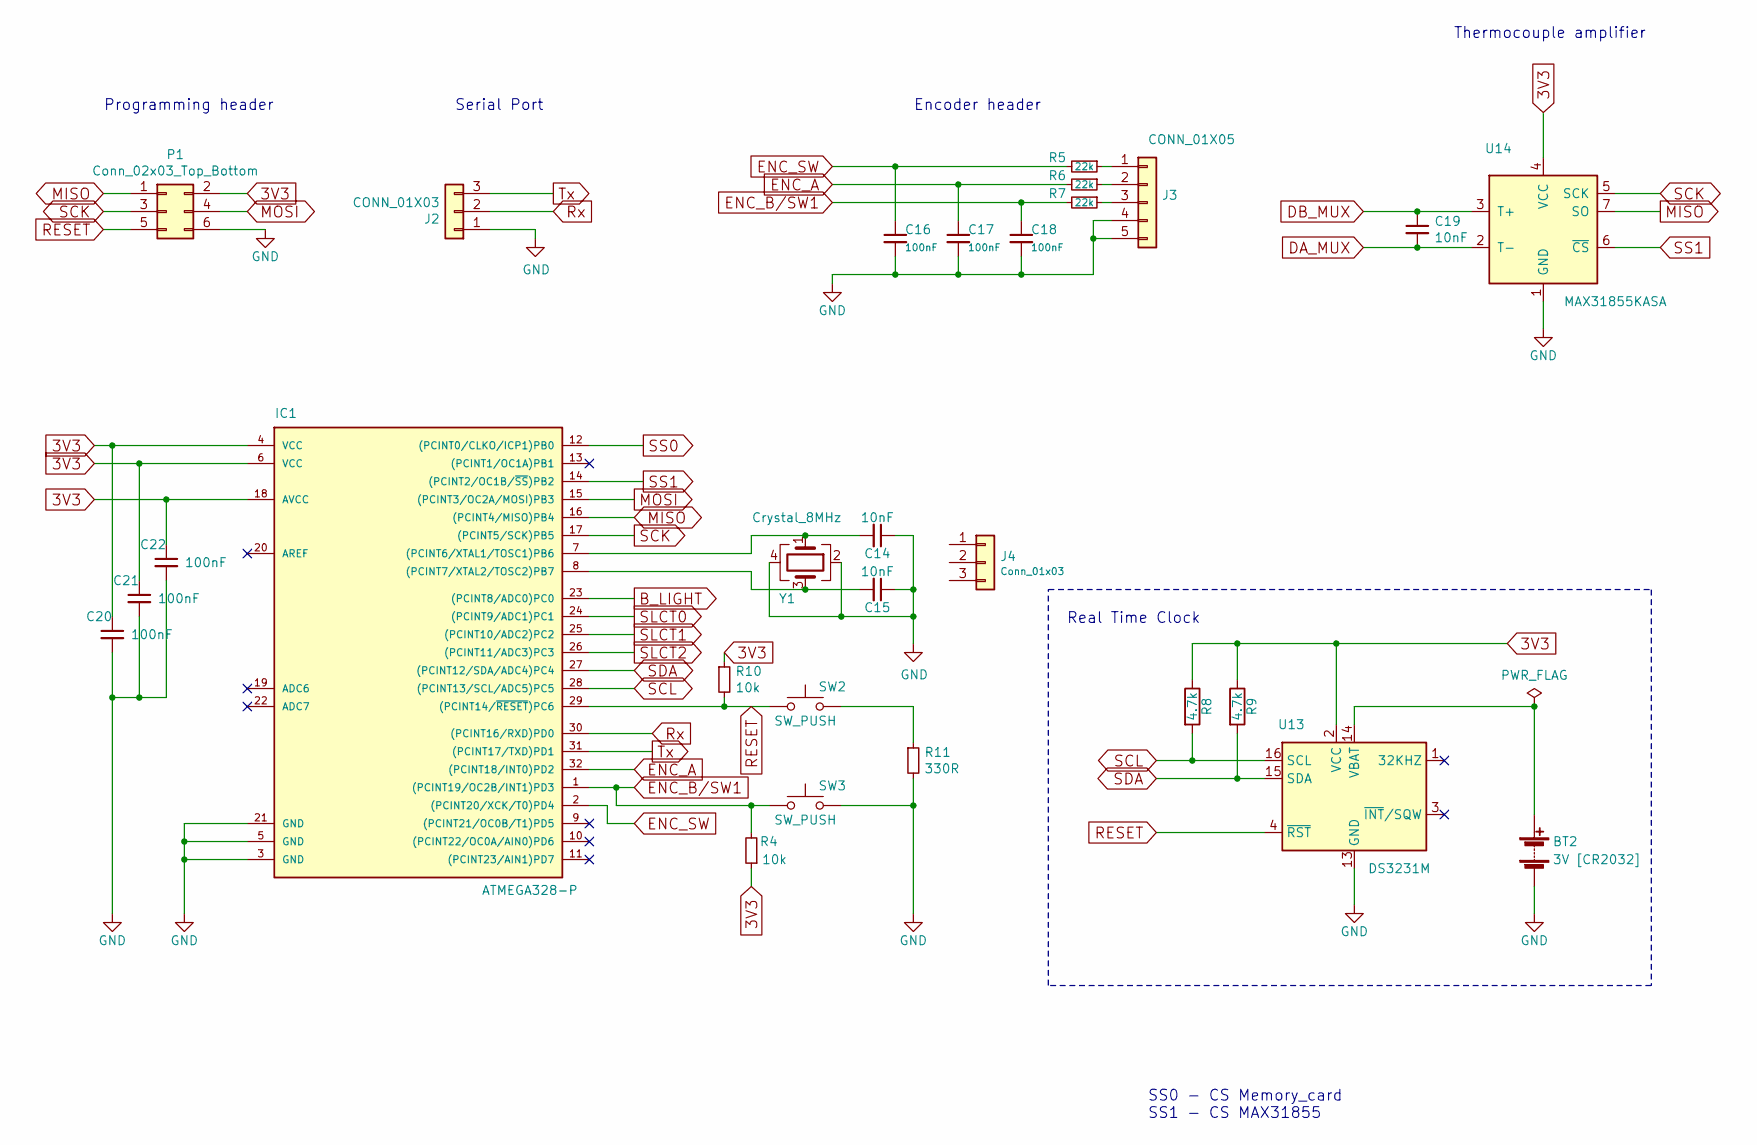
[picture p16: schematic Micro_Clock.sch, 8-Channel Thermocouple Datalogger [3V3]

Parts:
BT2: 3V [CR2032]; BatteryHolder_Keystone_103_1x20mm; Part# KEYSTONE 103
C14, C15, C19: 10nF; C_0805_2012Metric
C16, C17, C18, C20, C21, C22: 100nF; C_0805_2012Metric
IC1: ATMEGA328-P; LQFP-32_7x7mm_P0.8mm; Part# ATMEGA328P-AU
J2: CONN_01X03; PinHeader_1x03_P2.54mm_Vertical; Part# B3B-XH-A(LF)(SN)
J3: CONN_01X05; PinHeader_1x05_P2.54mm_Vertical; Part# B5B-XH-A(LF)(SN)
J4: Conn_01x03
P1: Conn_02x03_Top_Bottom; PinHeader_2x03_P2.54mm_Vertical; Part# 75869-131LF
R4, R10: 10k; R_0805_2012Metric
R5, R6, R7: 22k; R_0805_2012Metric
R8, R9: 4.7k; R_0805_2012Metric
R11: 330R; R_0805_2012Metric
SW2, SW3: SW_PUSH; SW_PUSH_6mm_H4.3mm; Part# SKHHAJA010
U13: DS3231M; SOIC-16W_7.5x10.3mm_P1.27mm
U14: MAX31855KASA; SOIC-8_3.9x4.9mm_P1.27mm; Part# MAX31855KASA
Y1: Crystal_8MHz; Crystal_SMD_Abracon_ABM3B-4Pin_5.0x3.2mm; Part# ABM3B-8.000MHZ-B2-T

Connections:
3V3: C20.1, C21.1, C22.1, IC1.4 (VCC), IC1.6 (VCC), IC1.18 (AVCC), P1.2, R4.1, R8.1, R9.1, R10.1, U13.2 (VCC), U14.4 (VCC); also elsewhere on the board
B_LIGHT: IC1.23 ((PCINT8/ADC0)PC0); also elsewhere on the board
DA_MUX: C19.2, U14.2 (T-); also elsewhere on the board
DB_MUX: C19.1, U14.3 (T+); also elsewhere on the board
ENC_A: C17.1, IC1.32 ((PCINT18/INT0)PD2), R6.2
ENC_B/SW1: C18.1, IC1.1 ((PCINT19/OC2B/INT1)PD3), R4.2, R7.2, SW3.1
ENC_SW: C16.1, IC1.2 ((PCINT20/XCK/T0)PD4), R5.2
GND: BT2.2 (-), C14.1, C15.1, C16.2, C17.2, C18.2, C20.2, C21.2, C22.2, IC1.3 (GND), IC1.5 (GND), IC1.21 (GND), J2.1, J3.4, J3.5, P1.6, R11.2, SW3.2, U13.5 (GND), U13.6 (GND), U13.7 (GND), U13.8 (GND), U13.9 (GND), U13.10 (GND), U13.11 (GND), U13.12 (GND), U13.13 (GND), U14.1 (GND), Y1.2, Y1.4; also elsewhere on the board
MISO: IC1.16 ((PCINT4/MISO)PB4), P1.1, U14.7 (SO); also elsewhere on the board
MOSI: IC1.15 ((PCINT3/OC2A/MOSI)PB3), P1.4; also elsewhere on the board
unnamed: BT2.1 (+), U13.14 (VBAT)
unnamed: C14.2, IC1.7 ((PCINT6/XTAL1/TOSC1)PB6), Y1.1
unnamed: C15.2, IC1.8 ((PCINT7/XTAL2/TOSC2)PB7), Y1.3
unnamed: J3.1, R5.1
unnamed: J3.2, R6.1
unnamed: J3.3, R7.1
unnamed: R11.1, SW2.2
RESET: IC1.29 ((PCINT14/~RESET~)PC6), P1.5, R10.2, SW2.1, U13.4 (~RST)
Rx: IC1.30 ((PCINT16/RXD)PD0), J2.2
SCK: IC1.17 ((PCINT5/SCK)PB5), P1.3, U14.5 (SCK); also elsewhere on the board
SCL: IC1.28 ((PCINT13/SCL/ADC5)PC5), R8.2, U13.16 (SCL); also elsewhere on the board
SDA: IC1.27 ((PCINT12/SDA/ADC4)PC4), R9.2, U13.15 (SDA); also elsewhere on the board
SLCT0: IC1.24 ((PCINT9/ADC1)PC1); also elsewhere on the board
SLCT1: IC1.25 ((PCINT10/ADC2)PC2); also elsewhere on the board
SLCT2: IC1.26 ((PCINT11/ADC3)PC3); also elsewhere on the board
SS0: IC1.12 ((PCINT0/CLKO/ICP1)PB0); also elsewhere on the board
SS1: IC1.14 ((PCINT2/OC1B/~SS~)PB2), U14.6 (~CS~)
Tx: IC1.31 ((PCINT17/TXD)PD1), J2.3

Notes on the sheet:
Programming header
Encoder header
Serial Port
SS0 - CS Memory_card SS1 - CS MAX31855
Real Time Clock
Thermocouple amplifier

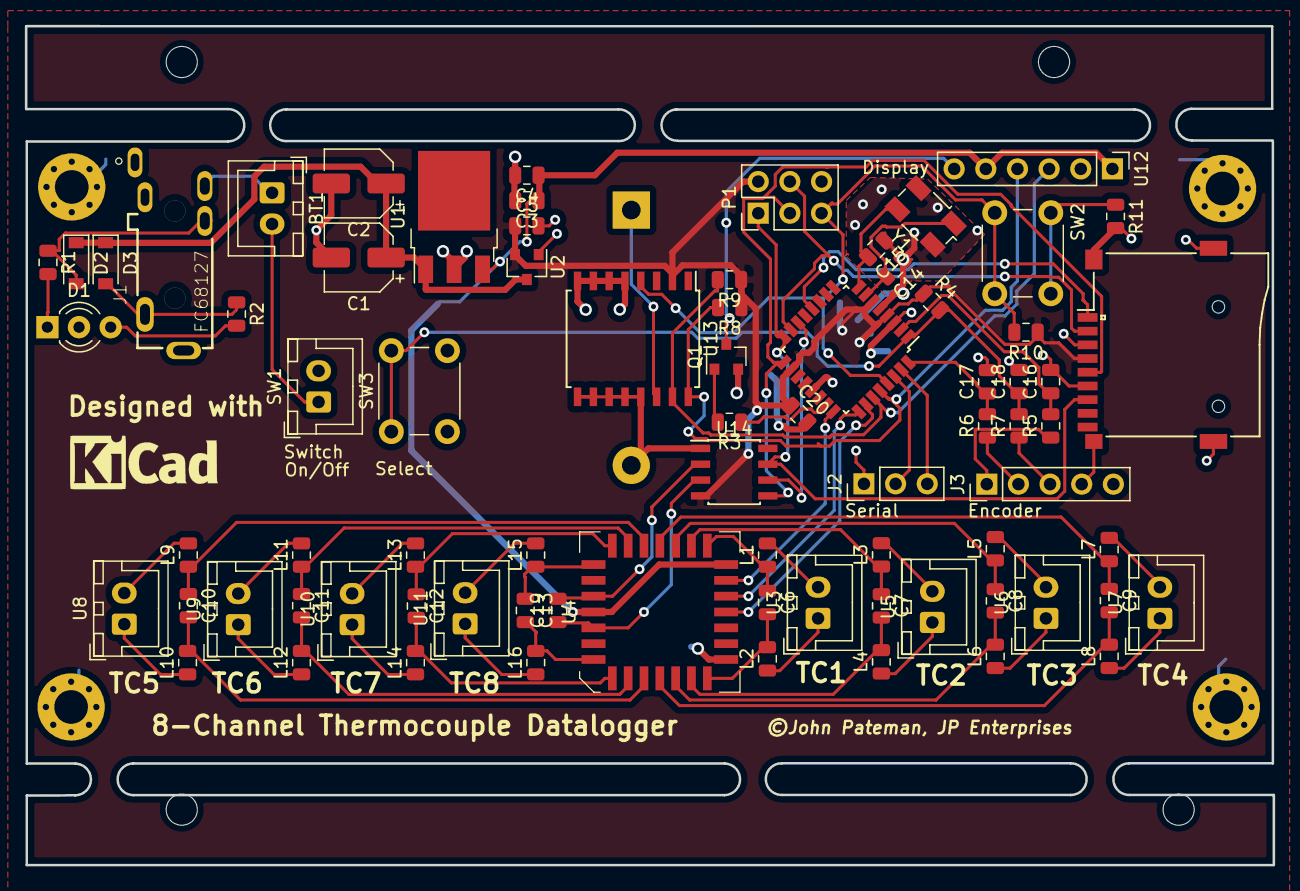
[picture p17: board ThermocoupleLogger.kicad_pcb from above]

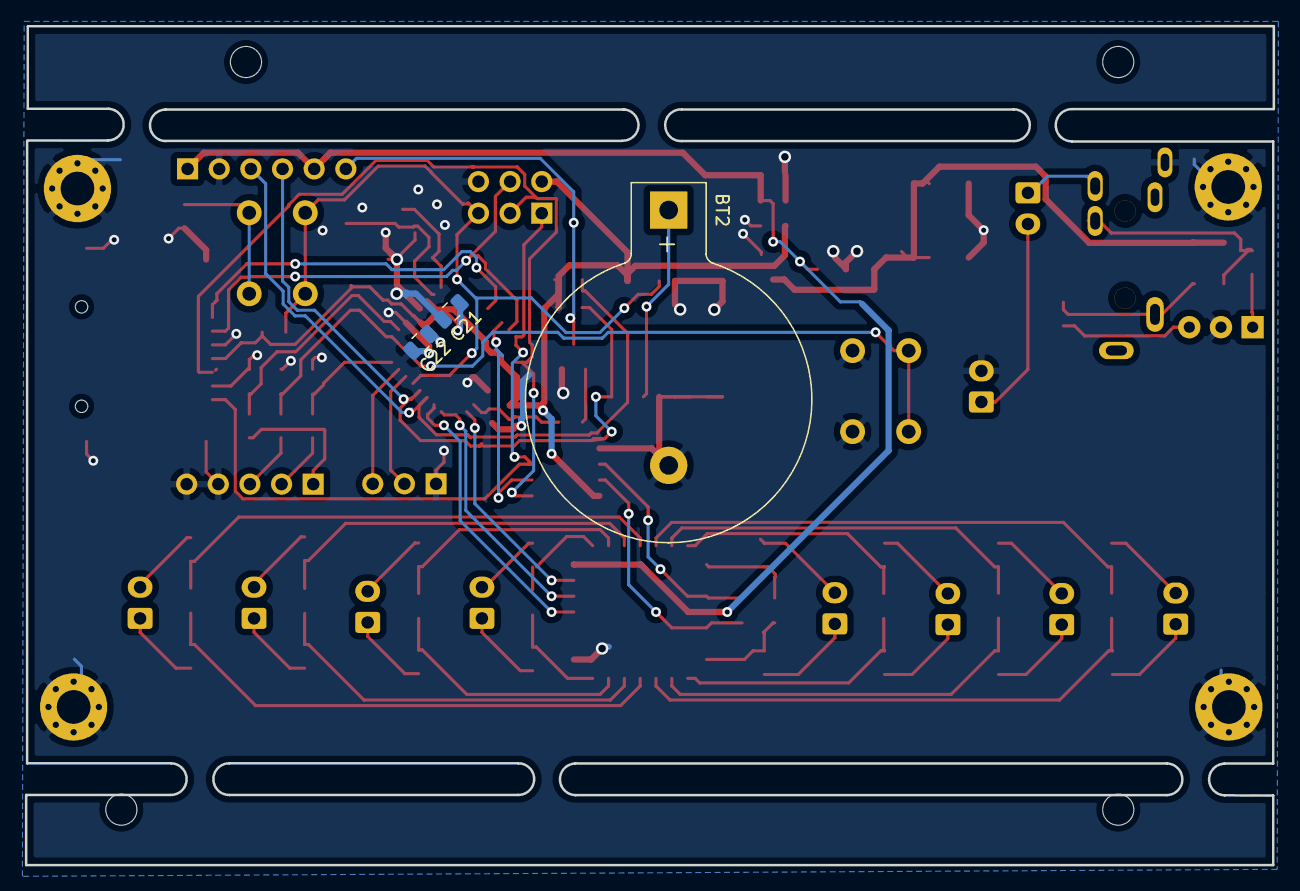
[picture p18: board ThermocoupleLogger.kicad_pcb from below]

Board: 2 copper layers, 100.1 x 67.3 mm, 87 parts (5 on the bottom side), 70 nets.

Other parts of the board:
FD1, FD2, FD3, FD4: Alignment_Hole_2.5mm

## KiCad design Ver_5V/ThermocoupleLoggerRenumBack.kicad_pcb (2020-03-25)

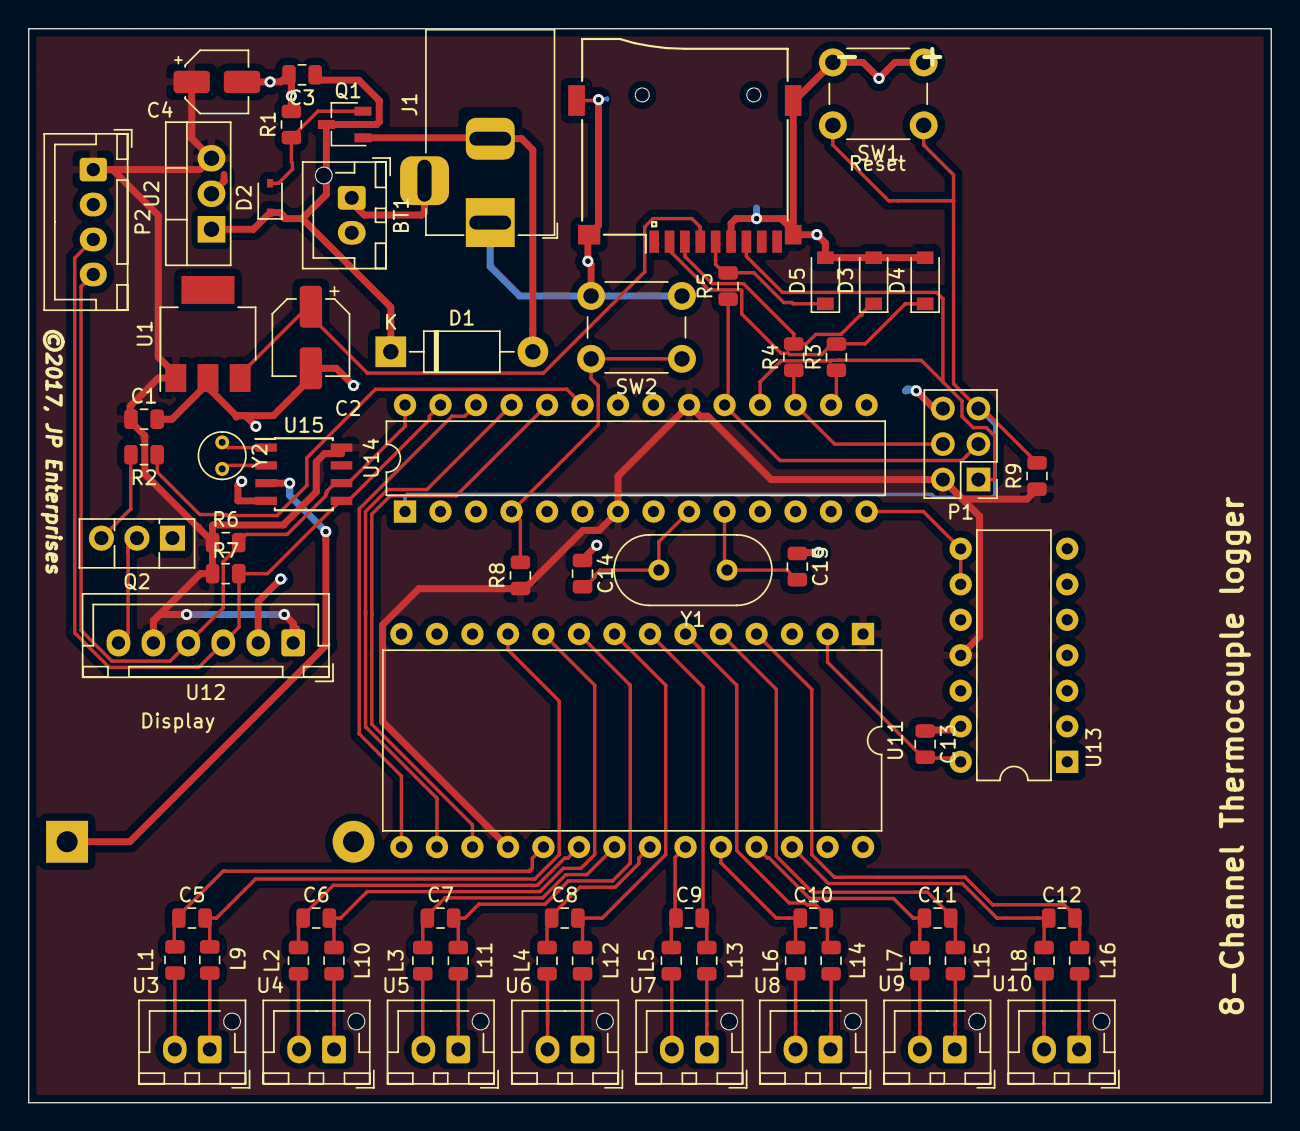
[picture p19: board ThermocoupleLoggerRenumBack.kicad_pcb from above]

Board: 2 copper layers, 88.9 x 76.8 mm, 72 parts (1 on the bottom side), 63 nets.

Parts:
BT1: 9V; JST_XH_B02B-XH-AM_1x02_P2.50mm_Vertical
BT2: Battery; BatteryHolder_Keystone_103_1x20mm
C1: 470nF; C_0805_2012Metric
C2: 47uF; CP_Elec_5x5.3
C3: 1uF; C_0805_2012Metric
C4: 10uF; CP_Elec_4x5.4
C5, C6, C7, C8, C9, C10, C11, C12, C13: 10nF; C_0805_2012Metric
C14, C15: 18pF; C_0805_2012Metric
D1: 1N4007; D_DO-41_SOD81_P10.16mm_Horizontal
D2: 9V; D_SOD-323
D3, D4, D5: 3.3V; D_SOD-123
J1: Barrel_Jack; BarrelJack_Horizontal
L1, L2, L3, L4, L5, L6, L7, L8, L9, L10, L11, L12, L13, L14, L15, L16: 150; L_0805_2012Metric
P1: CONN_02X03; PinHeader_2x03_P2.54mm_Vertical
P2: Conn_01x04; JST_XH_B04B-XH-A_1x04_P2.50mm_Vertical
Q1: BS250; TSOT-23
Q2: BD139; TO-126-3_Vertical
R1, R2, R8, R9: 10K; R_0805_2012Metric
R3, R4, R5: 220R; R_0805_2012Metric
R6, R7: 5.1K; R_0805_2012Metric
SW1, SW2: SW_Push; SW_PUSH_6mm_H5mm
U1: LM3940; SOT-223
U2: 7805; TO-220-3_Vertical
U3, U4, U5, U6, U7, U8, U9, U10: TC_Connector; JST_XH_B02B-XH-AM_1x02_P2.50mm_Vertical
U11: ADG407; DIP-28_W15.24mm
U12: I2C_20x4_DISPLAY; JST_XH_B06B-XH-A_1x06_P2.50mm_Vertical
U13: AD595; DIP-14_W7.62mm
U14: ATMEGA328P-PU; DIP-28_W7.62mm
U15: DS1307+; SOIC-8_3.9x4.9mm_P1.27mm
XS1: SD_ebay-uSD-push/push_SMD; Conn_uSDcard
Y1: 16MHz; Crystal_HC49-U_Vertical
Y2: 32.768kHz; Crystal_Round_D3.0mm_Vertical

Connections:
3V3: C2.1, U1.3, XS1.4
5V0: C1.1, C4.1, P1.2, P2.1, R6.1, R7.1, R8.1, R9.1, U1.1, U2.3, U11.1, U11.18, U12.1, U12.5, U13.11, U14.7, U14.20, U15.8
9V0: C3.1, D1.1, D2.1, Q1.3, U2.1
/Thermocouple connectors/SA1: C5.1, L1.1, U11.19
/Thermocouple connectors/SA2: C6.1, L2.1, U11.20
/Thermocouple connectors/SA3: C7.1, L3.1, U11.21
/Thermocouple connectors/SA4: C8.1, L4.1, U11.22
/Thermocouple connectors/SA5: C9.1, L5.1, U11.23
/Thermocouple connectors/SA6: C10.1, L6.1, U11.24
/Thermocouple connectors/SA7: C11.1, L7.1, U11.25
/Thermocouple connectors/SA8: C12.1, L8.1, U11.26
/Thermocouple connectors/SB1: C5.2, L9.2, U11.11
/Thermocouple connectors/SB2: C6.2, L10.2, U11.10
/Thermocouple connectors/SB3: C7.2, L11.2, U11.9
/Thermocouple connectors/SB4: C8.2, L12.2, U11.8
/Thermocouple connectors/SB5: C9.2, L13.2, U11.7
/Thermocouple connectors/SB6: C10.2, L14.2, U11.6
/Thermocouple connectors/SB7: C11.2, L15.2, U11.5
/Thermocouple connectors/SB8: C12.2, L16.2, U11.4
/Thermocouple_PSU/Supply: D1.2, J1.2, Q1.1
B_LIGHT: R2.1, U14.23
DB_MUX: C13.2, U11.2, U13.14
GND: BT1.2, BT2.2, C1.2, C2.2, C3.2, C4.2, C13.1, C14.1, C15.1, D3.2, D4.2, D5.2, J1.1, P1.6, P2.2, Q2.1, R1.2, SW1.2, SW2.2, U1.2, U2.2, U11.12, U11.28, U12.2, U13.1, U13.4, U13.7, U13.13, U14.8, U14.22, U15.4, XS1.6
MISO: P1.1, U14.18, XS1.7
MOSI: P1.4, R4.1, U14.17
unnamed: BT1.1, J1.3
unnamed: BT2.1, U15.3
unnamed: C14.2, U14.9, Y1.2
unnamed: C15.2, U14.10, Y1.1
unnamed: U15.1, Y2.1
unnamed: U15.2, Y2.2
unnamed: D2.2, Q1.2, R1.1
unnamed: D3.1, R4.2, XS1.3
unnamed: D4.1, R3.2, XS1.2
unnamed: D5.1, R5.2, XS1.5
unnamed: L1.2, U3.2
unnamed: L2.2, U4.2
unnamed: L3.2, U5.2
unnamed: L4.2, U6.2
unnamed: L5.2, U7.2
unnamed: L6.2, U8.2
unnamed: L7.2, U9.2
unnamed: L8.2, U10.2
unnamed: L9.1, U3.1
unnamed: L10.1, U4.1
unnamed: L11.1, U5.1
unnamed: L12.1, U6.1
unnamed: L13.1, U7.1
unnamed: L14.1, U8.1
unnamed: L15.1, U9.1
unnamed: L16.1, U10.1
unnamed: Q2.2, U12.6
unnamed: Q2.3, R2.2
unnamed: R8.2, SW2.1, U14.4
RESET: P1.5, R9.2, SW1.1, U14.1
SCK: P1.3, R5.1, U14.19
SCL: P2.4, R6.2, U12.4, U14.28, U15.6
SDA: P2.3, R7.2, U12.3, U14.27, U15.5
SLCT0: U11.17, U14.24
SLCT1: U11.16, U14.25
SLCT2: U11.15, U14.26
SS: R3.1, U14.16
TEMP: U13.8, U13.9, U14.14

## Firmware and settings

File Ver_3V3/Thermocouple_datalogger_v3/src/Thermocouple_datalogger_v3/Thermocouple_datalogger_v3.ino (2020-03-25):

#include <Arduino.h>

/* Version ammended to use a MAX31855 SPI thermocouple sensor as input.
   This runs on a 3V3 SPI bus so should integrate with a ATmega 328 Low Power microcontroller
   The I2C bus will also support logic at this level.


/*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
   This program is meant to read 8 thermocouple temperatures and save them to a SD card.
   The program relies on a Arduino with AVR 328, a SDcard and real time clock shield from
   Adafruit Industries, a 20x4 line LCD display, and an AD595 thermocouple amplifier
   hooked up to a ADG407B differential multiplexer (aka "mux") to read the 8 thermocouple lines.
   The AD595 amplifier will convert voltages from type K and type T thermocouples into a
   10mV/°C output. It is spec'd to work with type K thermocouples over the full range, but
   will read type T thermocouples accurately over the ~0 to ~50°C range that is relevant to
   most biological systems.

   The SD card and real time clock shield used here are sourced from Adafruit Industries
   https://www.adafruit.com/product/1141
   The tutorial for assembling and setting up the SD card and real time clock are here:
   https://learn.adafruit.com/adafruit-data-logger-shield
   You must have the real time clock initialized (by running the sketches outlined in the
   LadyAda tutorial or using the settime.ino or settime_exact.ino sketches in the RTClib
   library examples) before attempting to load and run this sketch on the Arduino. This
   shield and the code below should work with an Arduino Uno or similar models, but would
   require modification to work with an Arduino Due or other ARM-based boards that move
   the SPI and I2C pins around.

   The SdFat library used in this version can be obtained from
   https://github.com/greiman/SdFat Put the contents of the SdFat directory into your
   Arduino/libraries/ directory so that this sketch can find it.

   The RTClib used here comes from https://github.com/millerlp/RTClib and is just a
    fork of  https://github.com/MrAlvin/RTClib Put the contents
   of that repository into a folder called RTClib inside your Arduino/libraries/ directory.

 */

#include <Wire.h>
#include <SPI.h>
#include <Time.h>
#include <TimeLib.h>
#include <DS1307RTC.h>

#include "RTClib.h" // From https://github.com/millerlp/RTClib
#include "SdFat.h"

//#include <SdSpiCard.h>

//#include <SdFatConfig.h>
//#include <SysCall.h>
//#include <BlockDriver.h>
//#include <MinimumSerial.h>
//include <FatLib.h> // Not the stock Arduino SD library, use https://github.com/greiman/SdFat

#include <LiquidCrystal_I2C.h> //for the LCD display
#include "Adafruit_MAX31855.h"

volatile unsigned long lastSave = 0; // time value of last save. Relies on realtime clock
volatile unsigned long lcdTimeOut = 0; //timer for turning off LCD
volatile byte saveInterval = 10; //time between saves (units = seconds, not millis)
volatile byte lcdInterval= 60; //time to wait before shutting off LCD (units = seconds)
const byte reps = 9; //number of temp readings to average per channel (count from zero)

//Employing a HD44780 driven display directly uses 6 pins which leave few for alternative
//uses. If you want to add any other indicators/LED/Encoder etc to this project, it is easiest to
//use a display with an I2C backpack - this is much easier to integrate and uses the SDA/SCL lines.

LiquidCrystal_I2C lcd(0x3F); //RS,EN,DB4,DB5,DB6,DB7

//Note, when using "analog" pins as digital input/output, you need to refer to the pin
//numbers by their "digital" line # equivalents. Analog pins 0-5 are referred to as
//pins 14-19 respectively when used as digital I/O lines.
#define muxA0 15 //analog 1, control line for ADG407 mux
#define muxA1 16 //analog 2, control line for ADG407 mux
#define muxA2 17 //analog 3, control line for ADG407 mux
#define tempPin 0 // analog 0, where temperature values are read in
#define lcdLight 9  // Use this line to actuate a PN2222A transistor. Hook the base
// of the transistor to a 680ohm resistor and then to pin 9 of Arduino.
// Hook the emitter of the transistor to ground. Hook the collector of
// the transistor to the grounds of the LCD. For total shut-off
// of the LCD, run the backlight ground (pin 16) and the contrast
// pot ground to the collector. When pin 9 is pulled high, the
// ground of the LCD will be connected to ground and it will light up.
// The program will continue running and saving data even when the LCD
// is shut off.
#define button1 2 //This is the digital input for the control button during the setup loop
byte button1INT = 0; //This is the interrupt pin for the control button during the main loop
                     //The same button (button 1) is repurposed from its function in the setup
                     //loop to act as the interrupt now.

#define aref_voltage 1.1 // using internal voltage reference for maximum resolution

//These are NOT right!! Just for compilation testing
int maxSO = 10;
int maxSS0 = 11;
int maxSCK = 12;
Adafruit_MAX31855 kTC(maxSCK, maxSS0, maxSO);

DS1307RTC RTC; // define the Real Time Clock object
DateTime now; //define a time object "now", from the RTClib library

// The objects to talk to the SD card
// Sd2Card card;
// SdVolume volume;
// SdFile root;
// SdFile file;
// File logfile; // The object that represents our datafile
SdFat sd;
SdFile logfile;  // for sd card, this is the file object to be written to
const byte chipSelect = 10; // chip select pin for SD card, 10 for regular Arduino, 53 for Mega
// Define a character array to hold the filename. Newer versions of the
// SdFat library support long file names.
char filename[] = "YYYYMMDD_HHMM_XX.CSV";


/*Below we set up the data storage arrays for the temperature readings. This sketch uses a
   smoothing routine to avoid aliasing and to keep the temperature readings from fluctuating
   too quickly. A series of 10 analog readings will be taken for each channel (1-8) and stored
   in the array 'tempInArray'. For each channel, the 10 analog readings will be added
   up (n1+n2+n3...+n10) and stored in the array 'total'. Then the value in 'total' (one per channel)
   will be divided by the number of readings (10) to get an average value. This average value is
   converted to a temperature and displayed during the main loop */
const byte chs = 8; //Number of thermocouple channels we'll be reading
const byte numReadings = 10; //Number of readings we'll be storing for each channel
unsigned int tempInArray[numReadings][chs]; //create array to hold analog values, for 8 channels
byte index = 0; //index value to iterate through in main loop for keeping running average
unsigned int total[chs]; //array of totals, one value per channel

//*****************************************************************************************
// Error handling loop, from the tutorials at ladyada.net listed above
// If there is a problem accessing the SD card, this loop gets called to display a cryptic
// error message.
void error(char *str)
{
        lcd.clear();
        lcd.home();
        lcd.print("error: ");
        lcd.print(str);
        while(1) ;
}
//****************************************************************************************

//****************************************************************************************
// Setup loop
// In this loop we will set up all the digital/analog inputs and outputs, initialize the
// SD card, let the user set the data save interval and the lcd light timeout.
void setup(void)
{
        Wire.begin(); // You must start the Wire thing before attempting to read the real time clock
        analogReference(INTERNAL); //We use the internal voltage reference (bandgap reference) of the
                                   //AVR uC for the analog-to-digital conversion of the temperature.
                                   //This gives us good resolution (~0.1C) over the 0 to ~100C range
        pinMode(muxA2, OUTPUT); //multiplexer control pins
        pinMode(muxA1, OUTPUT); //multiplexer control pins
        pinMode(muxA0, OUTPUT); //multiplexer control pins
        pinMode(button1, INPUT); // button for selecting options during setup and turning on display
        digitalWrite(button1, HIGH); // set internal pullup resistor
        pinMode(lcdLight, OUTPUT); //pin to toggle power to LCD (this is connected to the PN2222A transistor)
        digitalWrite(lcdLight, HIGH); //turn on LCD intially
        lcd.print("8-Port Thermocouple");
        lcd.setCursor(0,1);
        lcd.print("     Datalogger");
         //greet the user.
        delay(350);
        //**************************************************************************
        //Show current date and time from real time clock
        now = RTC.now(); //get current time from real time clock, store value in 'now'
        lcd.setCursor(0,0);
        lcd.print("Time: ");
        lcd.setCursor(0,1);
        lcd.print(now.hour(),DEC); //display current hour value
        lcd.print(":");
        if (now.minute() < 10) {
                lcd.print("0"); //insert leading zero if minute value is less than 10
                lcd.print(now.minute(),DEC); //display current minute
        }
        else lcd.print(now.minute(),DEC); //display current minute
        lcd.print(":");
        if (now.second() < 10) {
                lcd.print("0"); //insert leading zero if seconds value is less than 10
                lcd.print(now.second(),DEC); //display current seconds
        }
        else lcd.print(now.second(),DEC); //display current seconds
        lcd.setCursor(0,2);
        lcd.print(now.year(),DEC); //display month value
        lcd.print(F("-"));
        lcd.print(now.month(),DEC); //display numeric day value
        lcd.print(F("-"));
        lcd.print(now.day(),DEC); //display year
        delay(3000);


        //*********************************************************
        //********** SD card initialization ************
        // Try SPI_FULL_SPEED, or SPI_HALF_SPEED if full speed produces
        // errors on a breadboard setup.
        if (!sd.begin(chipSelect, SPI_FULL_SPEED)) {
                lcd.setCursor(0,3);
                lcd.println(F("Card failed")); // Show error if failed
        }
        // Otherwise if initialization works, show user on LCD
        lcd.setCursor(0,3);
        lcd.println(F("card initialized"));
        delay(1500);
        lcd.clear();

        // Create new file on SD card using initFileName() function
        // This creates a filename based on the year + month + day
        // with a number indicating which number file this is on
        // the given day. The format of the filename is
        // YYMMDDXX.CSV where XX is the counter (00-99). The
        // function also writes the column headers to the new file.
        initFileName(now);

        lcd.clear();
        lcd.home();
        lcd.print(F("Logging to: "));
        lcd.setCursor(0,1);
        lcd.print(filename);
        delay(3000);
        lcd.clear();

        if (!RTC.begin()) {
                logfile.println(F("RTC failed"));
                lcd.clear();
                lcd.home();
                lcd.print(F("RTC failed"));
                delay(2500);
        }

        //***************************************************************************
        // Have user select save-data interval and lcd timeout
        // These two lines call sub-routines that are down at the bottom of this file
        saveInterval = saveInt(); //call saveInt sub-function and return value
        lcdInterval = lcdInt(); //call lcdInt sub-function and return value
        //*******************************************************************************

        // initialize analog temperature value array
        for (byte channel = 0; channel < chs; channel++) {
                for (byte i = 0; i < numReadings; i++) {
                        tempInArray[i][channel] = 0; //initialize all values to 0
                }
        }
        //A side-effect of initializing the storage array to all zeros is that the first 10 values
        //of temperatures displayed on screen will be inaccurate until we fill up the tempInArray
        //and get rid of the zeros

        now = RTC.now(); //update clock
        while (now.second() != 0 && now.second() != 10 && now.second() != 20 && now.second() != 30 && now.second() != 40 && now.second() != 50)
        { //try to start recording data on an even time interval
          //this can introduce a delay of up to 10 seconds
                now = RTC.now(); //update clock
        }
        //while loop should quit when the seconds value is some multiple of 10, including 0

        lastSave = now.unixtime() + 10; //initialize the lastSave value so that we can
                                        //determine when to save to the SD card. Note that we're
                                        //adding 10 seconds to the lastSave value to avoid saving
                                        //the inaccurate values reported during the initial startup
                                        //when tempInArray still contains zeros.
        lcdTimeOut = now.unixtime(); //initialize lcdTimeOut to determine when to shut off the lcd backlight

        //*********************
        //Establish an interrupt routine for button1, so that the user can turn the LCD backlight back on
        //after it automatically shuts off. Any time the user presses button1, the program will stop what
        //it's doing and go to the sub-routine 'timeReset' (listed near the bottom of this file) to
        //turn the LCD back on and reset the lcdTimeOut value.
        attachInterrupt(button1INT, timeReset, CHANGE); //interrupt calls "timeReset" function
        lcd.clear();

} //end of setup loop
//********************************************************************************

//********************************************************************************
// Main Loop
void loop(void)
{

        //******************************************************************************
        //first subtract the old value in this row of tempInArray from the running total
        for (byte channel = 0; channel < chs; channel++) {
                total[channel] = total[channel] - tempInArray[index][channel];
        }

        //run through mux channels, read a temperature value for each channel and
        //insert it into the appropriate location of tempInArray
        //first set mux channel to read
        for (byte channel = 0; channel < chs; channel++) {
                //use bitwise AND along with bitshift operator to send digital 0's and 1's
                //to the appropriate digital output pins to control the ADG407 mux.
                //The ADG407's truth table is conveniently arranged so that the
                //progression below will send the correct combination of 0 and 1
                //to the three digital pins to set a channel 1-8.
                digitalWrite(muxA0, (channel & 1));
                digitalWrite(muxA1, (channel & 2)>>1);
                digitalWrite(muxA2, (channel & 4)>>2);
                delay(2); //delay for 2 milliseconds to give the mux time to settle
                          //The ADG407 is spec'd to switch in less than 160 ns, so the
                          //wait time used here should be more than sufficient

                //Next we'll take a reading on the tempPin analog channel, and stick the
                //value in tempinArray in the appropriate location
                kTC.readCelsius();
                delay(20);
                tempInArray[index][channel] = kTC.readCelsius();
                //Note that because of the multiplexer, all temperature readings can be done on
                //the same analog input pin (tempPin) since all 8 channels are sequentially routed
                //to this pin.
        } //end of for loop 'channel'
          //We now have the array 'tempinArray' full of raw integer values read off the
          //analog input pin for each of the 8 channels.

        //Next calculate a new total value for each channel by adding on the new analog
        //value that was just read
        for (byte channel = 0; channel < chs; channel++) {
                total[channel] = total[channel] + tempInArray[index][channel];
        }

        index++; //increment index value
        if (index >= numReadings) { //wrap around if we've exceeding the value of numReadings
                index = 0;
        }
        //Finished with temperature measuring
        //**********************************************************************************

        //**********************************************************************************
        //Update LCD display with current temperature values
        delay(500); //temporary delay to make the LCD readable. Should implement a sleep
                    // function here to save some battery power.
        lcd.home(); //put cursor at start of LCD screen
        byte row = 0;
        for (byte i = 0; i <=6; i = i + 2) { //this loop runs 4 times, one for each row of LCD
                lcd.setCursor(0,row); //move cursor to next row for subsequent write commands
                lcd.print("Ch");
                lcd.print(i+1); //display channel number (i + 1)
                lcd.print(":");
                lcdPrintDouble((((total[i]/numReadings) * aref_voltage / 1024) * 100), 1);
                lcd.setCursor(10,row);
                lcd.print("Ch");
                lcd.print(i+2);
                lcd.print(":");
                lcdPrintDouble((((total[i+1]/numReadings) * aref_voltage / 1024) * 100), 1);
                row++; //increment row counter
        }

        //*********************************************************************************
        //Write data to SD card if it's time to save
        now = RTC.now(); //get current time from Real Time Clock

        if (now.unixtime() >= (lastSave + saveInterval)) //if new unix time is greater than
                                                         //lastSave + saveInterval
        {
                noInterrupts(); //shut off interrupts during SD card writing

                // Reopen logfile. If opening fails, notify the user
                if (!logfile.isOpen()) {
                        if (!logfile.open(filename, O_RDWR | O_CREAT | O_AT_END)) {
                                lcd.setCursor(0,3);
                                lcd.println(F("File reopen failed"));
                                // bitSet(PINB, 0); // toggle ERRLED to show error
                        }
                }


                lastSave = now.unixtime(); //update lastSave value
                logfile.print(now.unixtime());
                logfile.print(",");
                logfile.print(now.year(), DEC);
                logfile.print(F("-"));
                logfile.print(now.month(), DEC);
                logfile.print(F("-"));
                logfile.print(now.day(), DEC);
                logfile.print(F(" "));
                logfile.print(now.hour(), DEC);
                logfile.print(F(":"));
                logfile.print(now.minute(), DEC);
                logfile.print(F(":"));
                logfile.print(now.second(), DEC);
                logfile.print(F(","));
                //now save temperatures
                for (int i=0; i<=6; i++) { //write the first 7 temperatures in a loop
                        logfile.print(((total[i]/numReadings) * aref_voltage / 1024) * 100);
                        logfile.print(F(","));
                }
                logfile.println(((total[7]/numReadings) * aref_voltage / 1024) * 100);
                logfile.sync();
                logfile.close(); // close file again

                interrupts(); //turn interrupts back on
                //print save notification to LCD
                lcd.setCursor(19,0);
                lcd.print(F("S"));
                lcd.setCursor(19,1);
                lcd.print(F("A"));
                lcd.setCursor(19,2);
                lcd.print(F("V"));
                lcd.setCursor(19,3);
                lcd.print(F("E"));
                delay(400);
                for (byte i = 0; i<=3; i++) { //clear save notification
                        lcd.setCursor(19,i);
                        lcd.print(F(" "));
                }
        } //end of lastSave loop
          //check to see if it's time to shut off the LCD display to conserve power
        if (now.unixtime() > lcdTimeOut + lcdInterval + 3) {
                digitalWrite(lcdLight, LOW); //turn off LCD
        }
}  //end of main program loop
//**********************************************************************************


// sub-routines start below here
//**********************************************************************************
//Interrupt routine
void timeReset() { //this is called by the interrupt routine attached to interrupt 0
        static unsigned long last_interrupt_time = 0;
        unsigned long interrupt_time = millis();
        //If interrupts come faster than 200ms, ignore since it's probably button bounce
        if (interrupt_time - last_interrupt_time > 200) {
                digitalWrite(lcdLight, HIGH); //turn LCD on
                lcdTimeOut = now.unixtime(); //reset lcdTimeOut
        }
        last_interrupt_time = interrupt_time;
}
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

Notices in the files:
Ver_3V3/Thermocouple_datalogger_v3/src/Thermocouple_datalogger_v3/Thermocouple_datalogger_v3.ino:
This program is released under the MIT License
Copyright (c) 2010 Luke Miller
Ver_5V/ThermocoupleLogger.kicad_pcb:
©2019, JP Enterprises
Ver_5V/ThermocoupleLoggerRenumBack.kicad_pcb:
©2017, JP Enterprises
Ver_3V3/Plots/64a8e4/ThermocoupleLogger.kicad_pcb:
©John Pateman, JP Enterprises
